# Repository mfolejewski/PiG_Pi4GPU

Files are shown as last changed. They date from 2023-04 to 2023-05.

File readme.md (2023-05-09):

# PiG (Pi4GPU)
Raspberry Pi CM4 carrier board for testing GPU cards

## Description

Dedicated carrier board for Raspberry Pi CM4 module (and compatible models) for testing high-performance GPU cards, enclosed in the standard PCIe form factor card.

Technical specification:
- ports: HDMI, 1GbE RJ45, 2x USB 2.0 host (Type A);
- power supply inputs: 12VDC DC barrel jack or 6-pin Molex (8A max.);
- microSD slot for CM4 Lite module;
- full 40-pin GPIO pin header;
- 4-pin fan socket (controlled by EMC2301) - 5/12V version supported;
- USB-C for flashing CM4 module;
- system and user LEDs;
- PCIe x4 edge connector (PCIe x1 lane only implemented);
- I2C diagnostics module for analog measurements (system power rails, 3.3V/5V/12V, voltage/current);

## License

Project published as Open Source Hardware (OSHW) under CERN OHL v1.2 (Open Hardware License).



Project has been certified as Open Source Hardware by the Open Source Hardware Association (OSHWA).

UID is (for v1): PL000014

UID is (for v2): PL000016

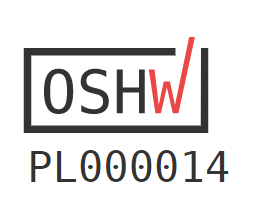
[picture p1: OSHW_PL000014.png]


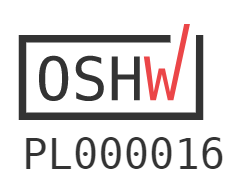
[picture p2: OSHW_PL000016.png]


https://certification.oshwa.org/pl000014.html

https://certification.oshwa.org/pl000016.html

## Press release

[Jeff Geerling Blog] (https://www.jeffgeerling.com/blog/2023/i-built-special-pcie-card-test-gpus-on-pi)

[Jeff Geerling video review] (https://www.youtube.com/watch?v=l9dItRUjQ0k)

[Hackster.io] (https://www.hackster.io/news/jeff-geerling-s-pig-makes-it-easier-to-experiment-with-pcie-add-in-boards-on-the-raspberry-pi-cm4-fdb977047521)

## Photos
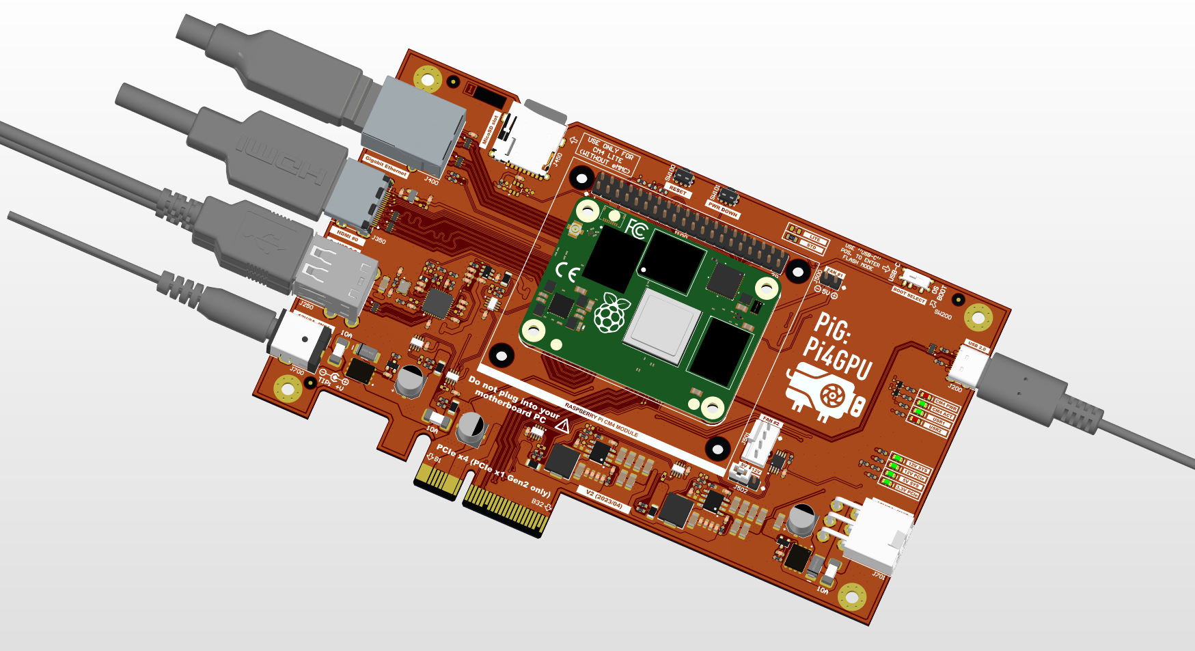
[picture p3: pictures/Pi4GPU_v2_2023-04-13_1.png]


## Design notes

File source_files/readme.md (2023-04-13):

## PCB design - source files
Here the design files (schematic, PCB, BOM) can be viewed by using interactive service (Altium 365 platform): 
- v1: https://365.altium.com/files/16D52066-6CA6-4288-87DA-874B35C8B3C8
- v2: https://365.altium.com/files/2EB381B2-202C-4C54-8FDE-9D991AE2ABAC

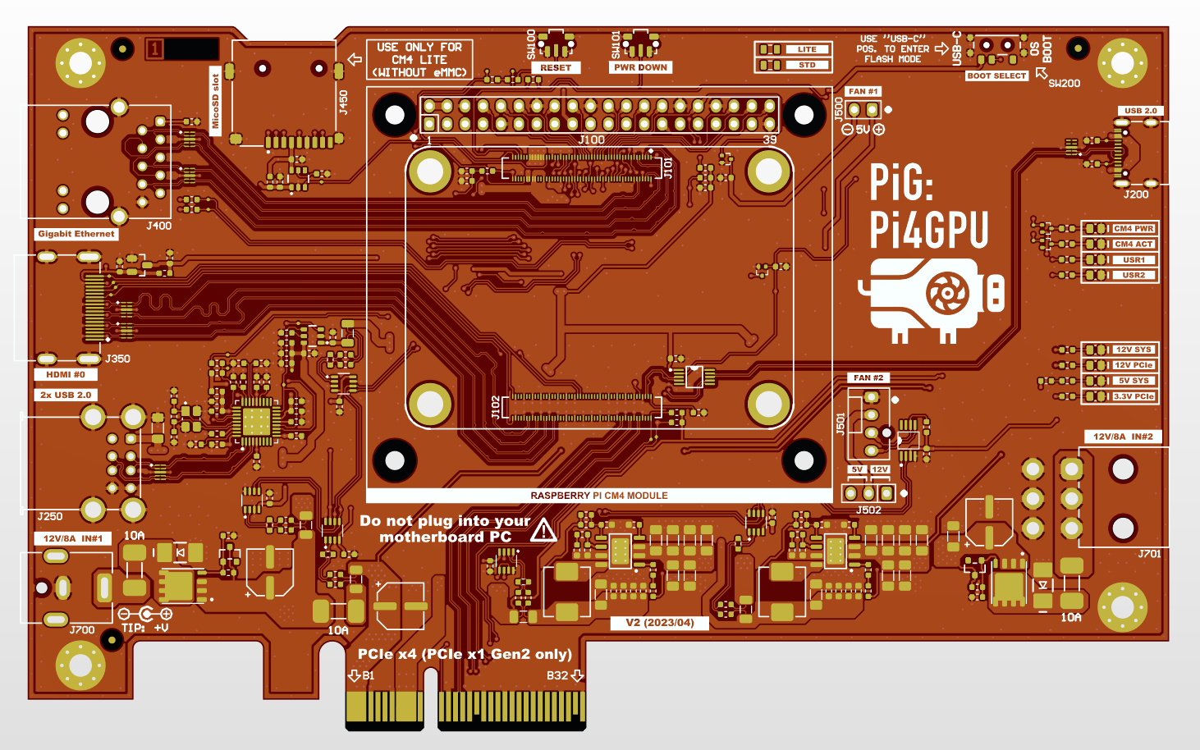
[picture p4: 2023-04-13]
pictures/Pi4GPU_v2_2023-04-13_5.png

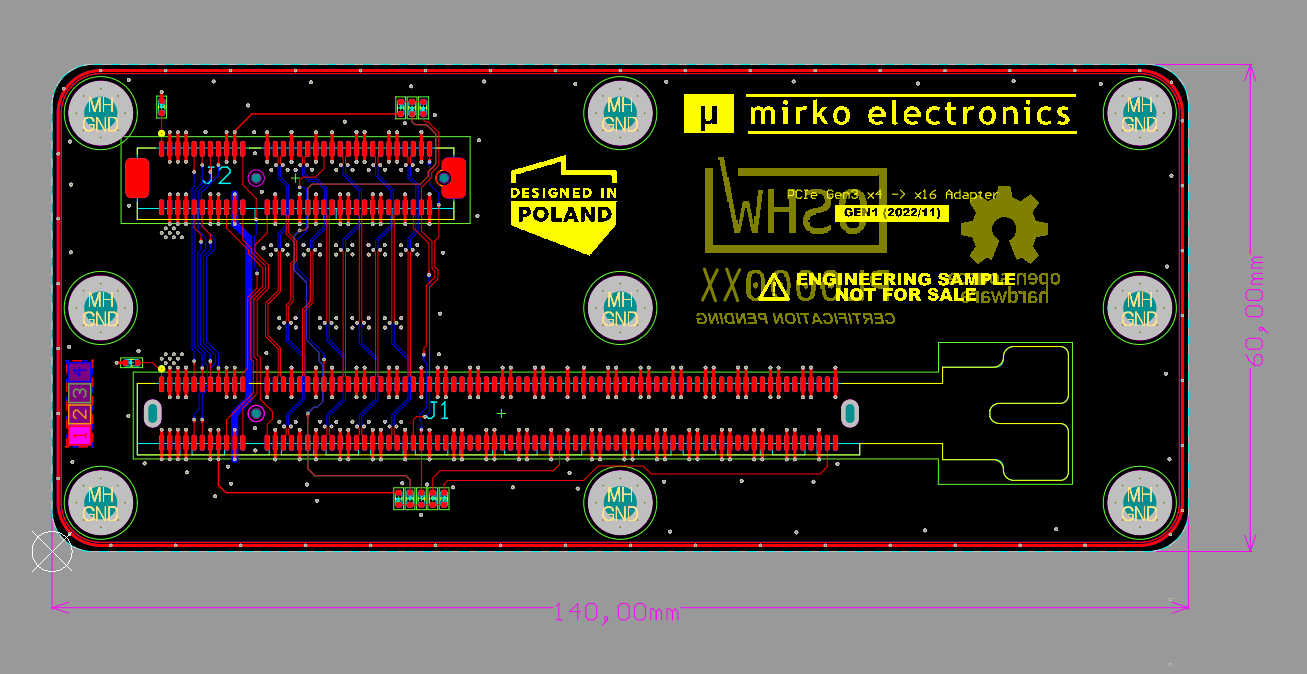
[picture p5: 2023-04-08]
pictures/PCIe_X4_X16_ADP_3.png

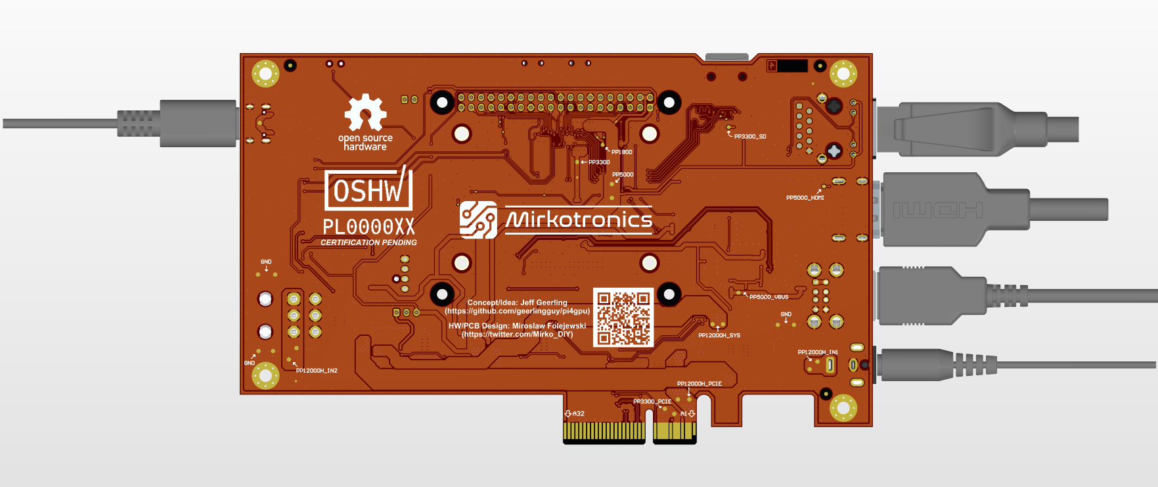
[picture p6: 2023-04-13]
pictures/Pi4GPU_v2_2023-04-13_3.png

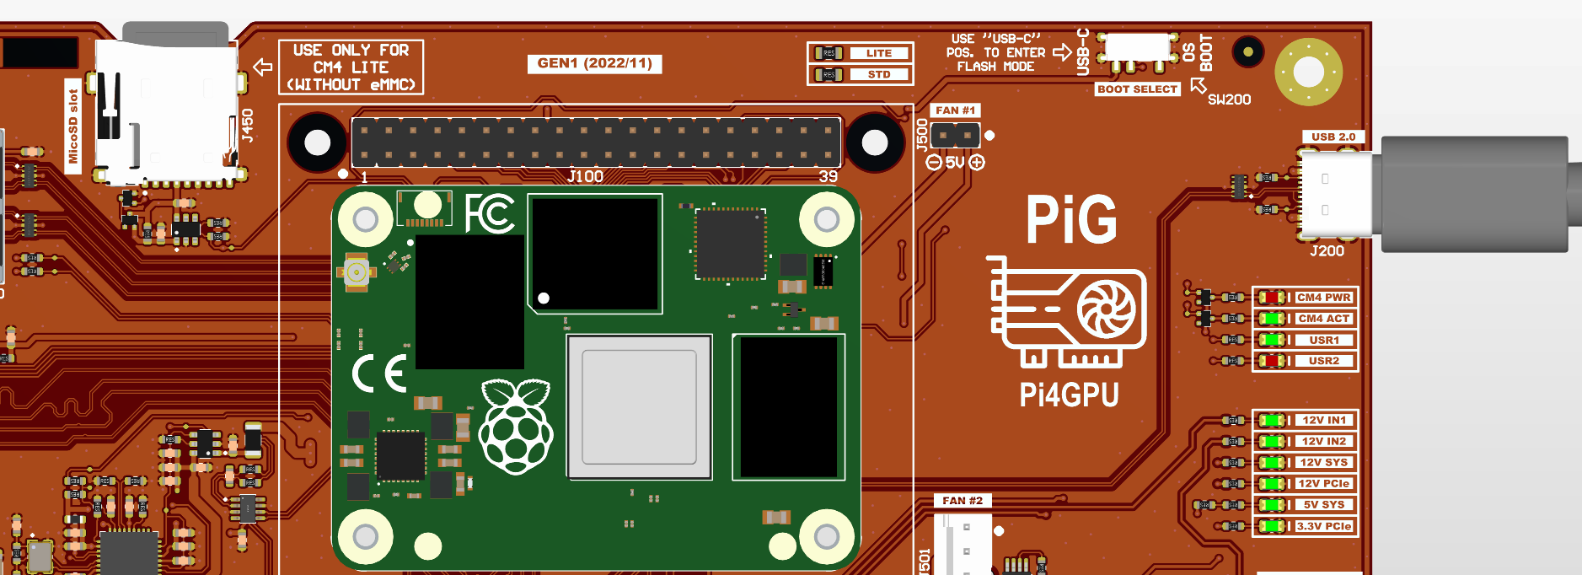
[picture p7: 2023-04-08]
pictures/Pi4GPU_2022-11-29_5.png

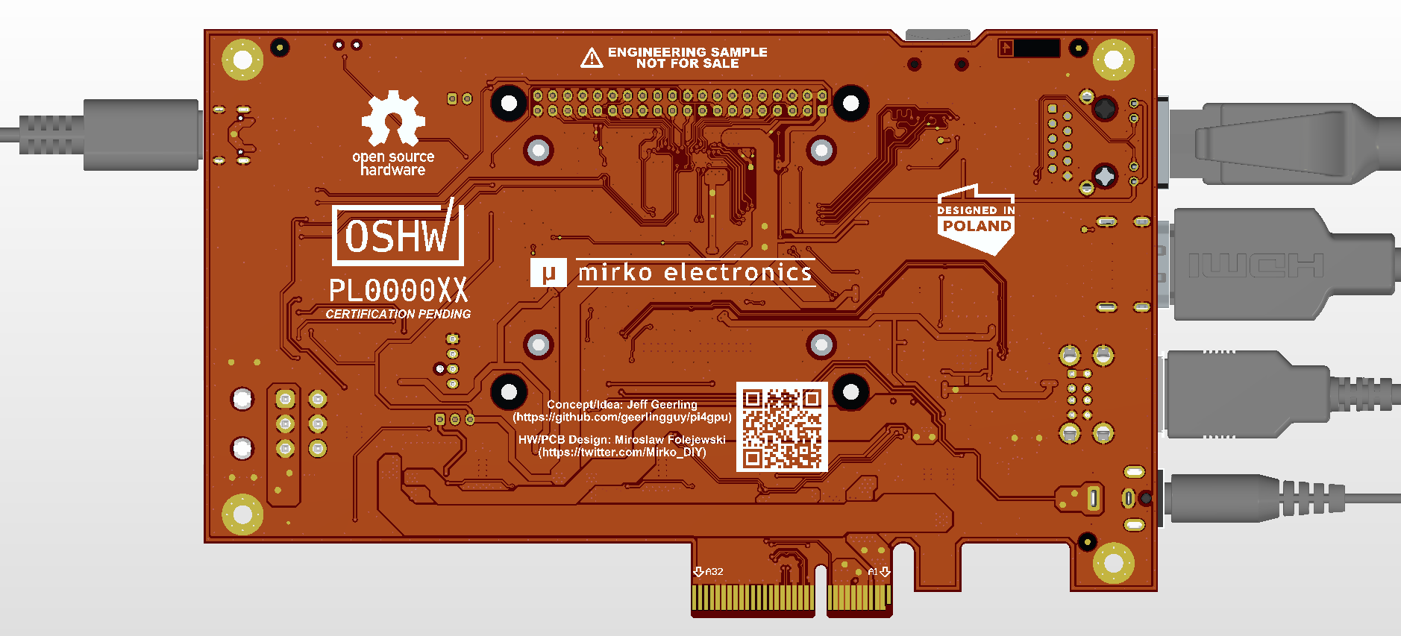
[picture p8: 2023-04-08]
pictures/Pi4GPU_2022-11-29_2.png

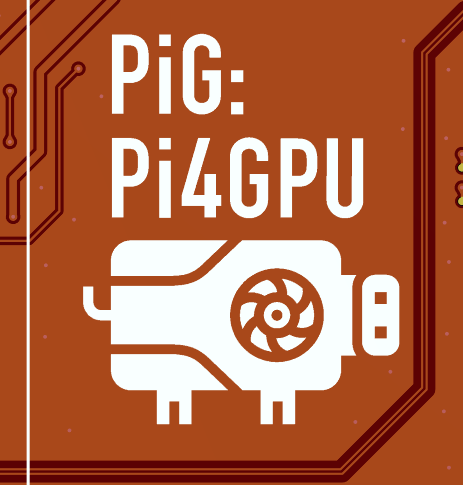
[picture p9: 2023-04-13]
pictures/Pi4GPU_v2_2023-04-13_4.png

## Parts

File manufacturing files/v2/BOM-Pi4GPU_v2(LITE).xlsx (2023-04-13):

Designator | Comment | Quantity | MPN | Manufacturer | Package (Case) | Footprint | Supplier 1 | Supplier Part Number 1
R450 | 0R | 1 | GENERIC | GENERIC | 0603 (1608) | RES_0603_R | LCSC | C21189
R900 | 0R | 1 | TBD | TBD | 0805 (2012) | RES_0805_R | LCSC | C17477
R807 | 0.004R | 1 | GENERIC | GENERIC | 1206 (3216) | RES_1206_R | LCSC | C5120913
R800, R806, R812 | 0.012R | 3 | GENERIC | GENERIC | 1206 (3216) | RES_1206_R | LCSC | C723448
R801 | 0.016R | 1 | GENERIC | GENERIC | 1206 (3216) | RES_1206_R | LCSC | C2904218
R200, R203 | 1k | 2 | TBD | Yageo Corporation | 0603 (1608) | RES_0603_R | LCSC | C21190
R256 | 1M | 1 | TBD | Yageo Corporation | 0603 (1608) | RES_0603_R | LCSC | C22935
C765, C781 | 1.2nF | 2 | GENERIC | GENERIC | 0603 (1608) | CAP_0603_R | LCSC | C1853470
R101, R102, R104, R106, R502 | 2k | 5 | TBD | Yageo Corporation | 0603 (1608) | RES_0603_R | LCSC | C22975
R760 | 2k26 | 1 | TBD | Yageo Corporation | 0603 (1608) | RES_0603_R | LCSC | C22904
L750, L751 | 3.3uH | 2 | FXL0624-3R3-M | Changjiang Microelectronics Tech | SMD | IND_SUM_0624CDMCCDS_700X660X240_R | LCSC | C524605
C256, C261 | 4u7 | 2 | GENERIC | GENERIC | 0603 (1608) | CAP_0603_R | LCSC | C19666
R201, R202 | 5k1 | 2 | TBD | Yageo Corporation | 0603 (1608) | RES_0603_R | LCSC | C23186
J700 | 8A, 2.0mm | 1 | PJ-063AH | CUI Devices | THT | CON_CUI_PJ-063AH | Mouser | 490-PJ-063AH
FUS700, FUS701, FUS702 | 10A/125VDC | 3 | 0679L9100-01 | Bel Fuse |  | FUS_2410_R | LCSC | C2838934
R103, R252, R253, R254, R255 | 10k | 5 | RC0603FR-0710KL | Yageo Corporation | 0603 (1608) | RES_0603_R | LCSC | C98220
R750, R755 | 10R | 2 | TBD | Yageo Corporation | 0603 (1608) | RES_0603_R | LCSC | C22859
C250, C252, C253, C254, C255, C451 | 10uF | 6 | GENERIC | GENERIC | 0603 (1608) | CAP_0603_R | LCSC | C19702
C755, C756, C757, C758, C771, C772, C773, C774 | 10uF/10V | 8 | GENERIC | GENERIC | 0603 (1608) | CAP_0603_R | LCSC | C19702
C703, C751, C752, C753, C761, C762, C763, C767, C768, C769, C777, C778, C779 | 10uF/35V | 13 | GENERIC | GENERIC | 1206 (3216) | CAP_1206_R | LCSC | C92797
R250 | 12k | 1 | GENERIC | GENERIC | 0603 (1608) | RES_0603_R | LCSC | C22790
R251, R753, R757 | 12k | 3 | TBD | Yageo Corporation | 0603 (1608) | RES_0603_R | LCSC | C22790
D700, D702 | 12V | 2 | MMBZ5242BLT3G | ON Semi |  | PKG_SOT23-3_TO236 | LCSC | C896784
R105, R501, R703, R709, R751, R756, R758 | 15k | 7 | TBD | Yageo Corporation | 0603 (1608) | RES_0603_R | LCSC | C22809
R754 | 15k | 1 | GENERIC | GENERIC | 0603 (1608) | RES_0603_R | LCSC | C22809
C266, C267 | 18pF | 2 | TBD | TBD | 0603 (1608) | CAP_0603_R | LCSC | C1647
R759 | 20k | 1 | GENERIC | GENERIC | 0603 (1608) | RES_0603_R | LCSC | C4184
X250 | 24.000MHz | 1 |  |  |  | OSC_3225_4P_R | LCSC | C5261153
J100 | 40pin (2x20pin) | 1 | GENERIC | GENERIC |  | CON_HDR_P254_2X20M_STR | LCSC | C124383
R752 | 47k | 1 | RC0603FR-0747KL | Yageo Corporation | 0603 (1608) | RES_0603_R | LCSC | C25819
R700, R701 | 100k | 2 | TBD | Yageo Corporation | 0603 (1608) | RES_0603_R | LCSC | C25803
C200, C257, C258, C259, C260, C262, C263, C350, C351, C400, C750, C760, C766, C776, C803 | 100nF | 15 | TBD | TBD | 0603 (1608) | CAP_0603_R | LCSC | C14663
C700, C702 | 100nF/50V | 2 | TBD | TBD | 0603 (1608) | CAP_0603_R | LCSC | C14663
R100, R107, R108, R109, R258 | 100R | 5 | TBD | Yageo Corporation | 0603 (1608) | RES_0603_R | LCSC | C22775
C251 | 100uF/6V3 | 1 | GENERIC | GENERIC | 1206 (3216) | CAP_1206_R | LCSC | C15008
C759, C775 | 100uF/10V | 2 | GENERIC | GENERIC | 1206 (3216) | CAP_1206_R | LCSC | C15008
F250 | 120 Ohm | 1 | TBD | TBD | 0603 (1608) | FER_0603_R | LCSC | C62708
C701, C704, C705 | 220uF/25V | 3 | EEEFTE221XAP | Panasonic | SMD SIZE D8 | CAP_SMD_SIZE_D8 | LCSC | C2918361
R400, R401 | 470R | 2 | TBD | Yageo Corporation | 0603 (1608) | RES_0603_R | LCSC | C23179
U352 | AP2331 | 1 | AP2331W-7 | Diodes Incorporated | SC59 | PKG_SOT23-3L_SC59_P190_R | LCSC | C460346
U250 | AP2553W6-7 | 1 | AP2553W6-7 | Diodes Incorporated | SOT26 | PKG_SOT23-6 | LCSC | C212302
U750, U751 | AP64501SP-13 | 2 | AP64501SP-13 | Diodes Incorporated |  | ICC_SOIC8N_TP_R | LCSC | C2071517
J500 | CON HDR 1x2 | 1 | GENERIC | GENERIC | THT | CON_HDR_P254_1X02_STR | LCSC | C492401
Q100, Q101 | DTA143ZE | 2 | DTA143ZET1G | On Semiconductor |  | PKG_SOT523_SC75_SOT416_P100_R | LCSC | C600679
Q200, Q500 | DTC143ZE | 2 | DTC143ZE |  |  | PKG_SOT523_SC75_SOT416_P100_R | LCSC | C248787
U200 | FSUSB42 | 1 | FSUSB42MUX | ON Semiconductor | MSOP-10 | ICC_MSOP10_300X300H110_P50_R | LCSC | C255478
LED100, LED500, LED700, LED701, LED750, LED751 | Green | 6 | NCD0805G1 | Foshan NationStar Optoelectronics | 0805 (2012) | LED_0805_GRN_R | LCSC | C84260
J400 | HY911130A | 1 | HY911130A | HanRun |  | CON_WRT_7499110122 | LCSC | C55679
J101, J102 | Mezzanine, 100pin, 3.0mm | 2 | DF40HC(3.0)-100DS-0.4V | Hirose | SMD | PCB_BLANK_COMP_SMD | LCSC | C424649
J450 | MicroSD Card (Slot) | 1 | TF-015 | TF-015 | SMD | CON_GCT_MEM2055_R | LCSC | C113206
J701 | Molex 2x3P 4.2mm | 1 | 039-30-1060 | Molex | THT | CON_MLX_039301060 | LCSC | C54904
PCB1 | PCB BARE BOARD | 1 | N/A | -
Q700, Q703 | PMOS | 2 | SI7149ADP-T1-GE3 | Vishay | PowerPAK-SO-8 | ICC_SO8_POWERPAK_490X590X112_P127_R | LCSC | C554002
U201, U252, U350, U351, U400, U401 | RCLAMP0524PA | 6 | RCLAMP0524PATCT | Semtech Corporation | TBD | ICC_SLP2510P8_250X100X60_P50_R | LCSC | C40960
LED101, LED501 | Red | 2 | NCD0805R1 | Foshan NationStar Optoelectronics | 0805 (2012) | LED_0805_RED_R | LCSC | C84256
MOD100 | RPi CM4 Module | 1 | CM4 Module | Raspberry Pi Foundation |  | MOD_RPI_CM4_SOCKET_P40_C300 | Farnell
SW200 | Slide switch | 1 | SS-3292S-L1 | XKB Connectivity | SMD | SWI_XKB_SS-3292S-L1 | LCSC | C397350
D701, D703 | SMAJ12A | 2 | SMAJ12A | Littelfuse |  | DIO_SMA_UNI_R | LCSC | C713694
SW100, SW101 | SPST | 2 | 436 333 033 816 | Wurth Elektronik | SMD | SWI_WRT_436333033816 | LCSC | C110293
J350 | Standdard HDMI (Type A) | 1 | HDMI-001 | BOOMELE | SMD | CON_HDMI_STD | LCSC | C138388
J200 | U262-161N-4BVC11 | 1 | U262-161N-4BVC11 | XKB Connectivity | SMD | CON_XKB_U262-161N-4BVC11 | LCSC | C319148
U251 | USB2512B | 1 | USB2512B | Microchip Technology |  | ICC_QFN36_600X600X100_P50_EP_R | LCSC | C626658
J250 | USB Type A (Dual) | 1 | TBD | TBD | THT | CON_USB_TYPE_A_2X | LCSC | C456021

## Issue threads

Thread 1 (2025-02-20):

Project tolerances and clearances

philm001, 2025-02-20:
Hello,

I am looking to this design for inspiration for a layout that I am working related to the one in here. I am currently using KiCAD. I was able to open the board layout but there are a number of DRC violations.

What are the tolerances and clearances for the board layout used to create the board.

philm001, 2025-02-21:
Never mind, I was able to come up with a solution and it clears the DRC

Closed 2025-02-21.

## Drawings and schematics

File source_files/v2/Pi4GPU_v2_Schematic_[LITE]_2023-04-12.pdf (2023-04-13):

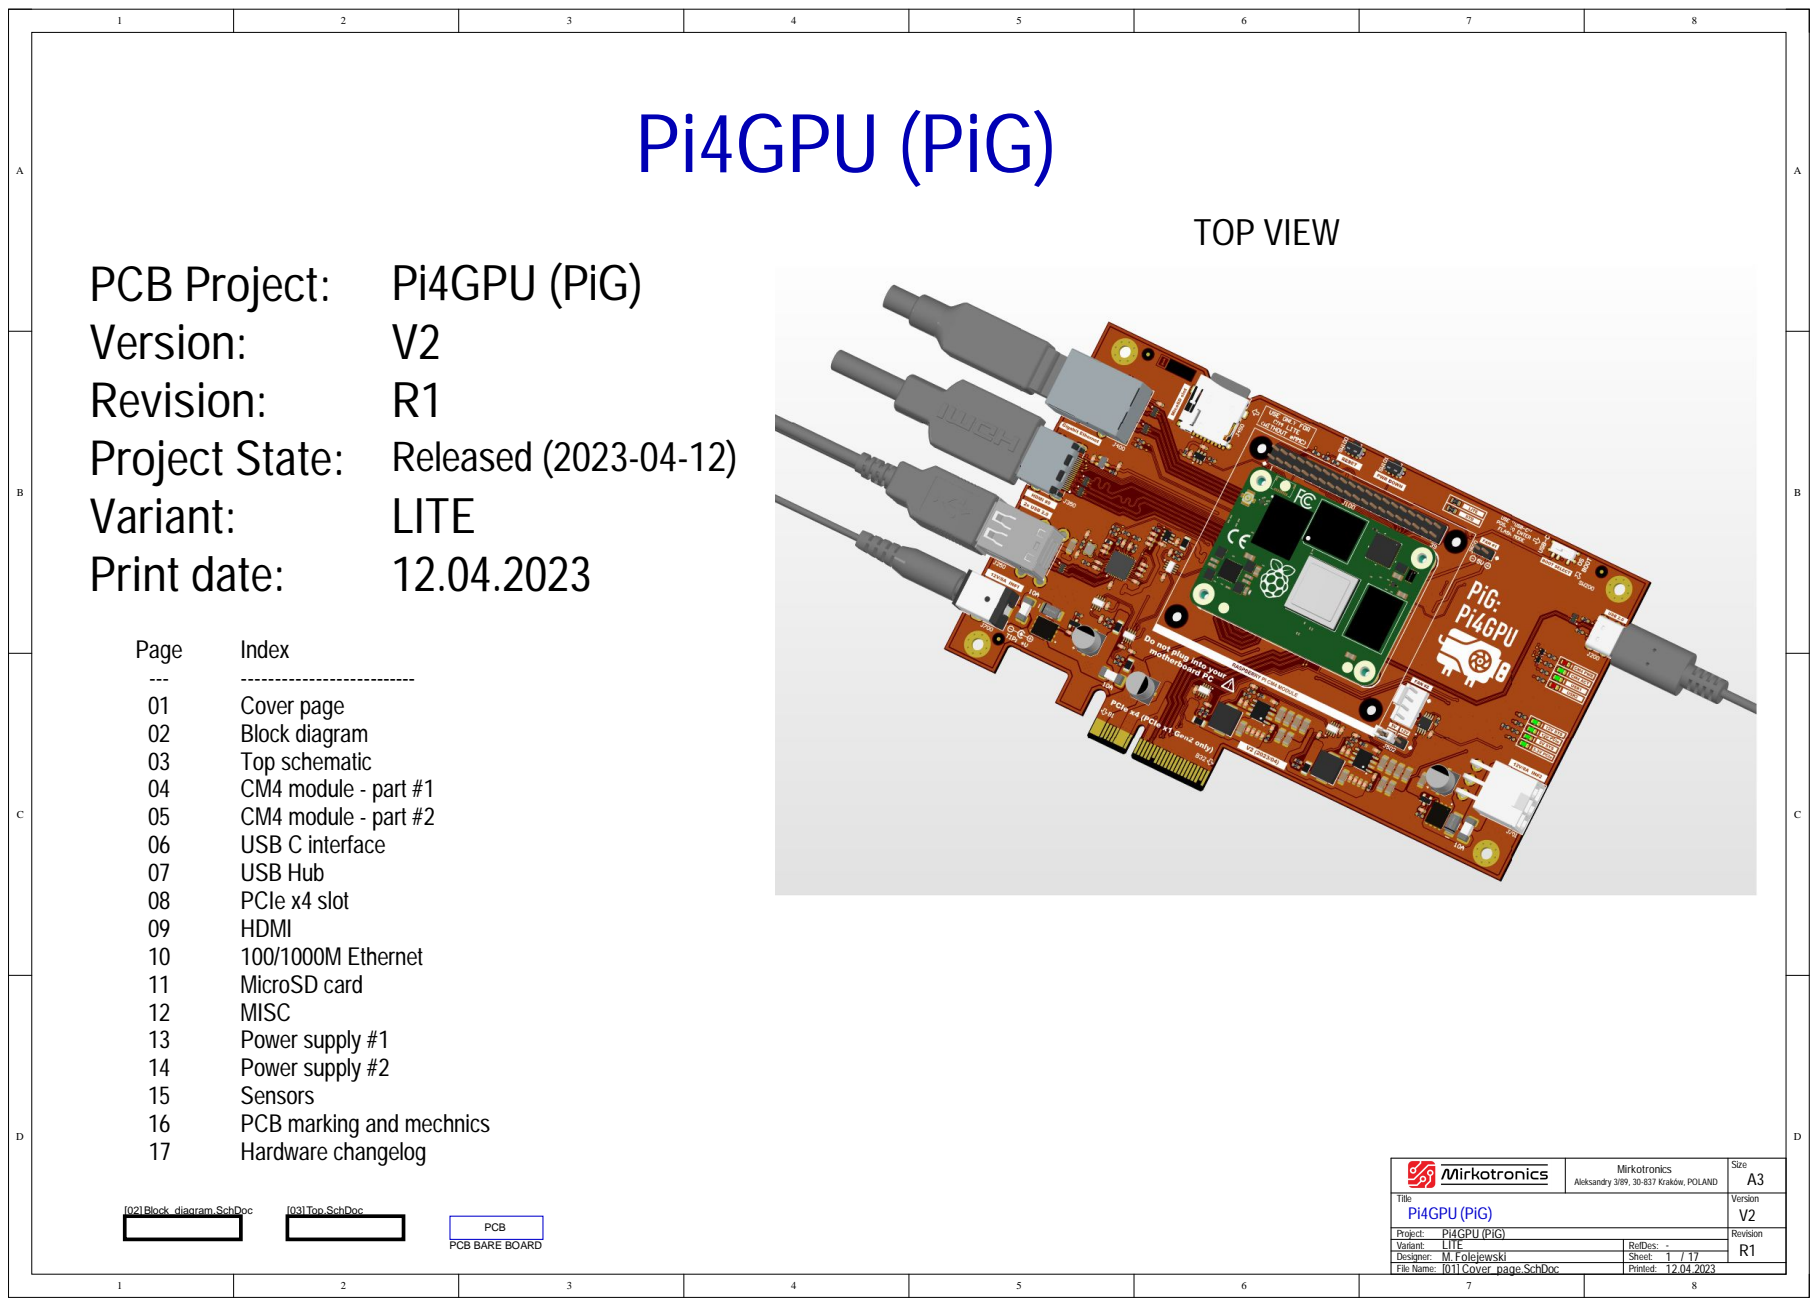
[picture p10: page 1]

Mirkotronics Aleksandry 3/89, 30-837 Kraków, POLAND | Size A3

Title Pi4GPU (PiG) | | Version V2

Revision R1
Variant: LITE
Designer: M. Folejewski
File Name: [01] Cover_page.SchDoc | Printed:

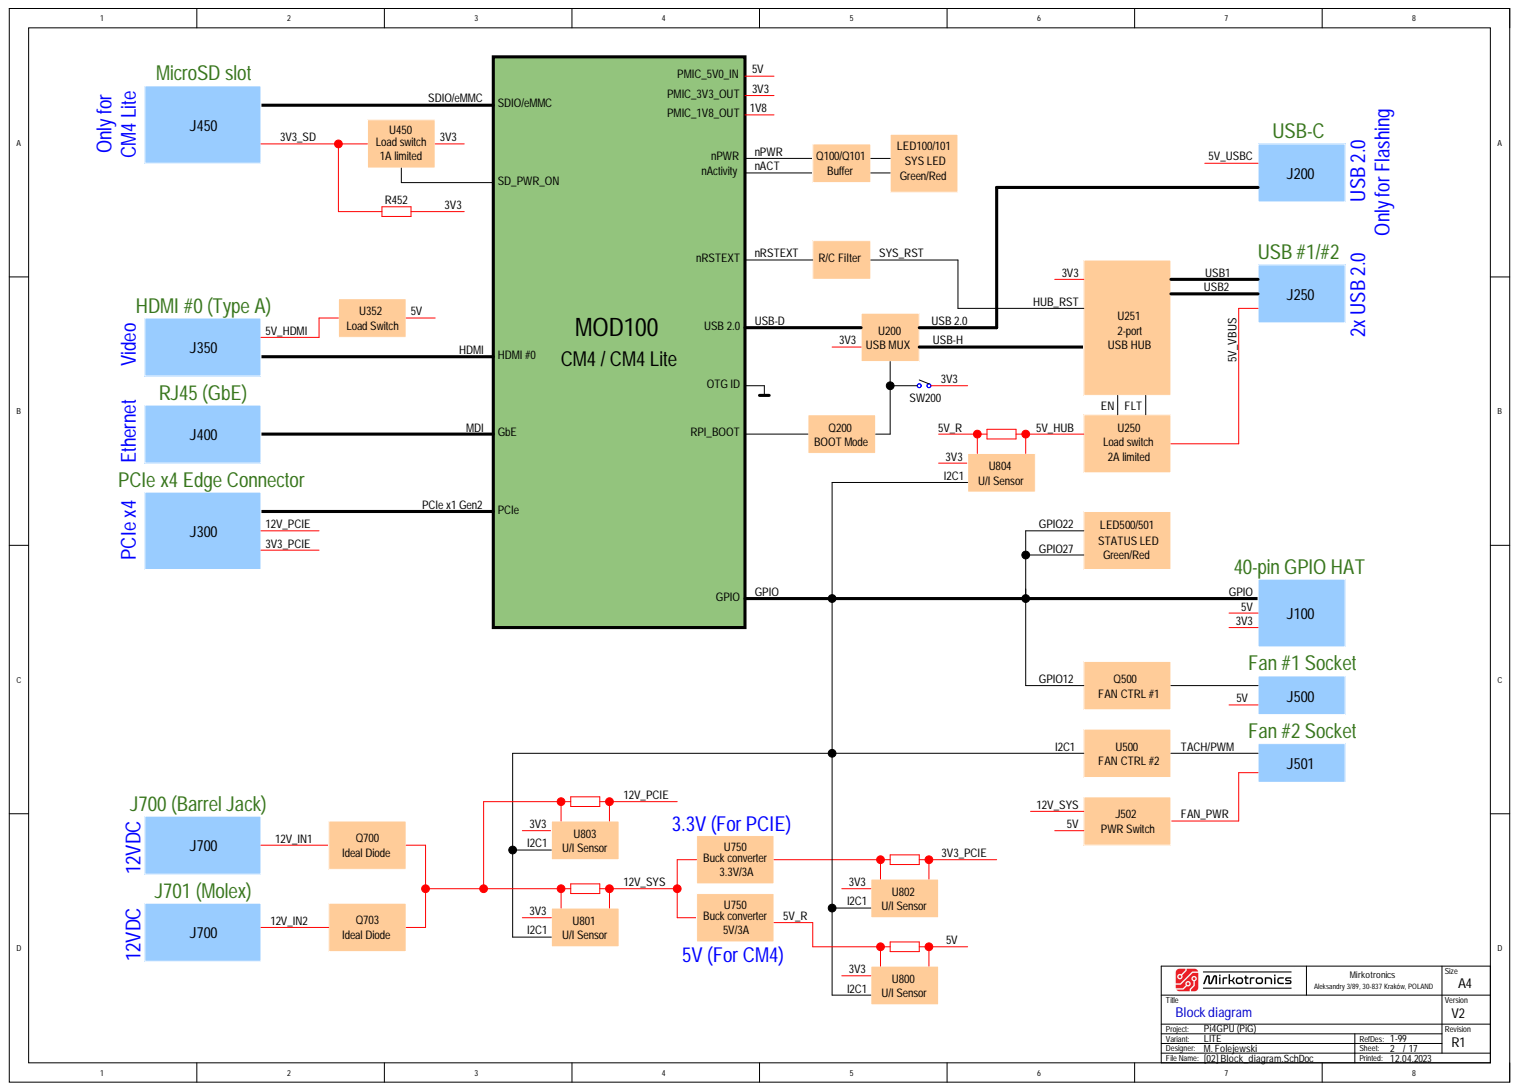
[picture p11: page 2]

SDIO/eMMC

Title Block diagram | Version V2

Revision R1
Variant: LITE

File Name: [02] Block_diagram.SchDoc | Printed:

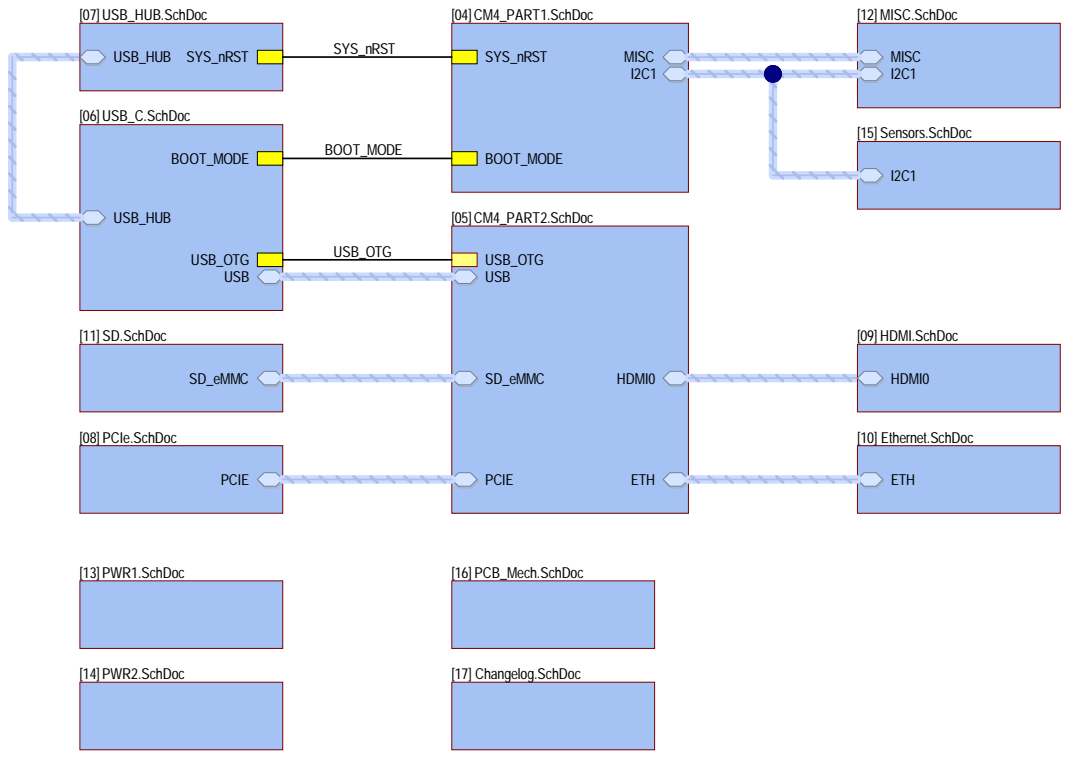
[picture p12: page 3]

Mirkotronics Aleksandry 3/89, 30-837 Kraków, POLAND | Size A4

Title Top schematic | | Version V2

Project: Pi4GPU (PiG) | | Revision R1
Variant: LITE | RefDes: 1-99

Sheet: 3 17 /

File Name: [03] TOP.SchDoc | Printed: 12.04.2023

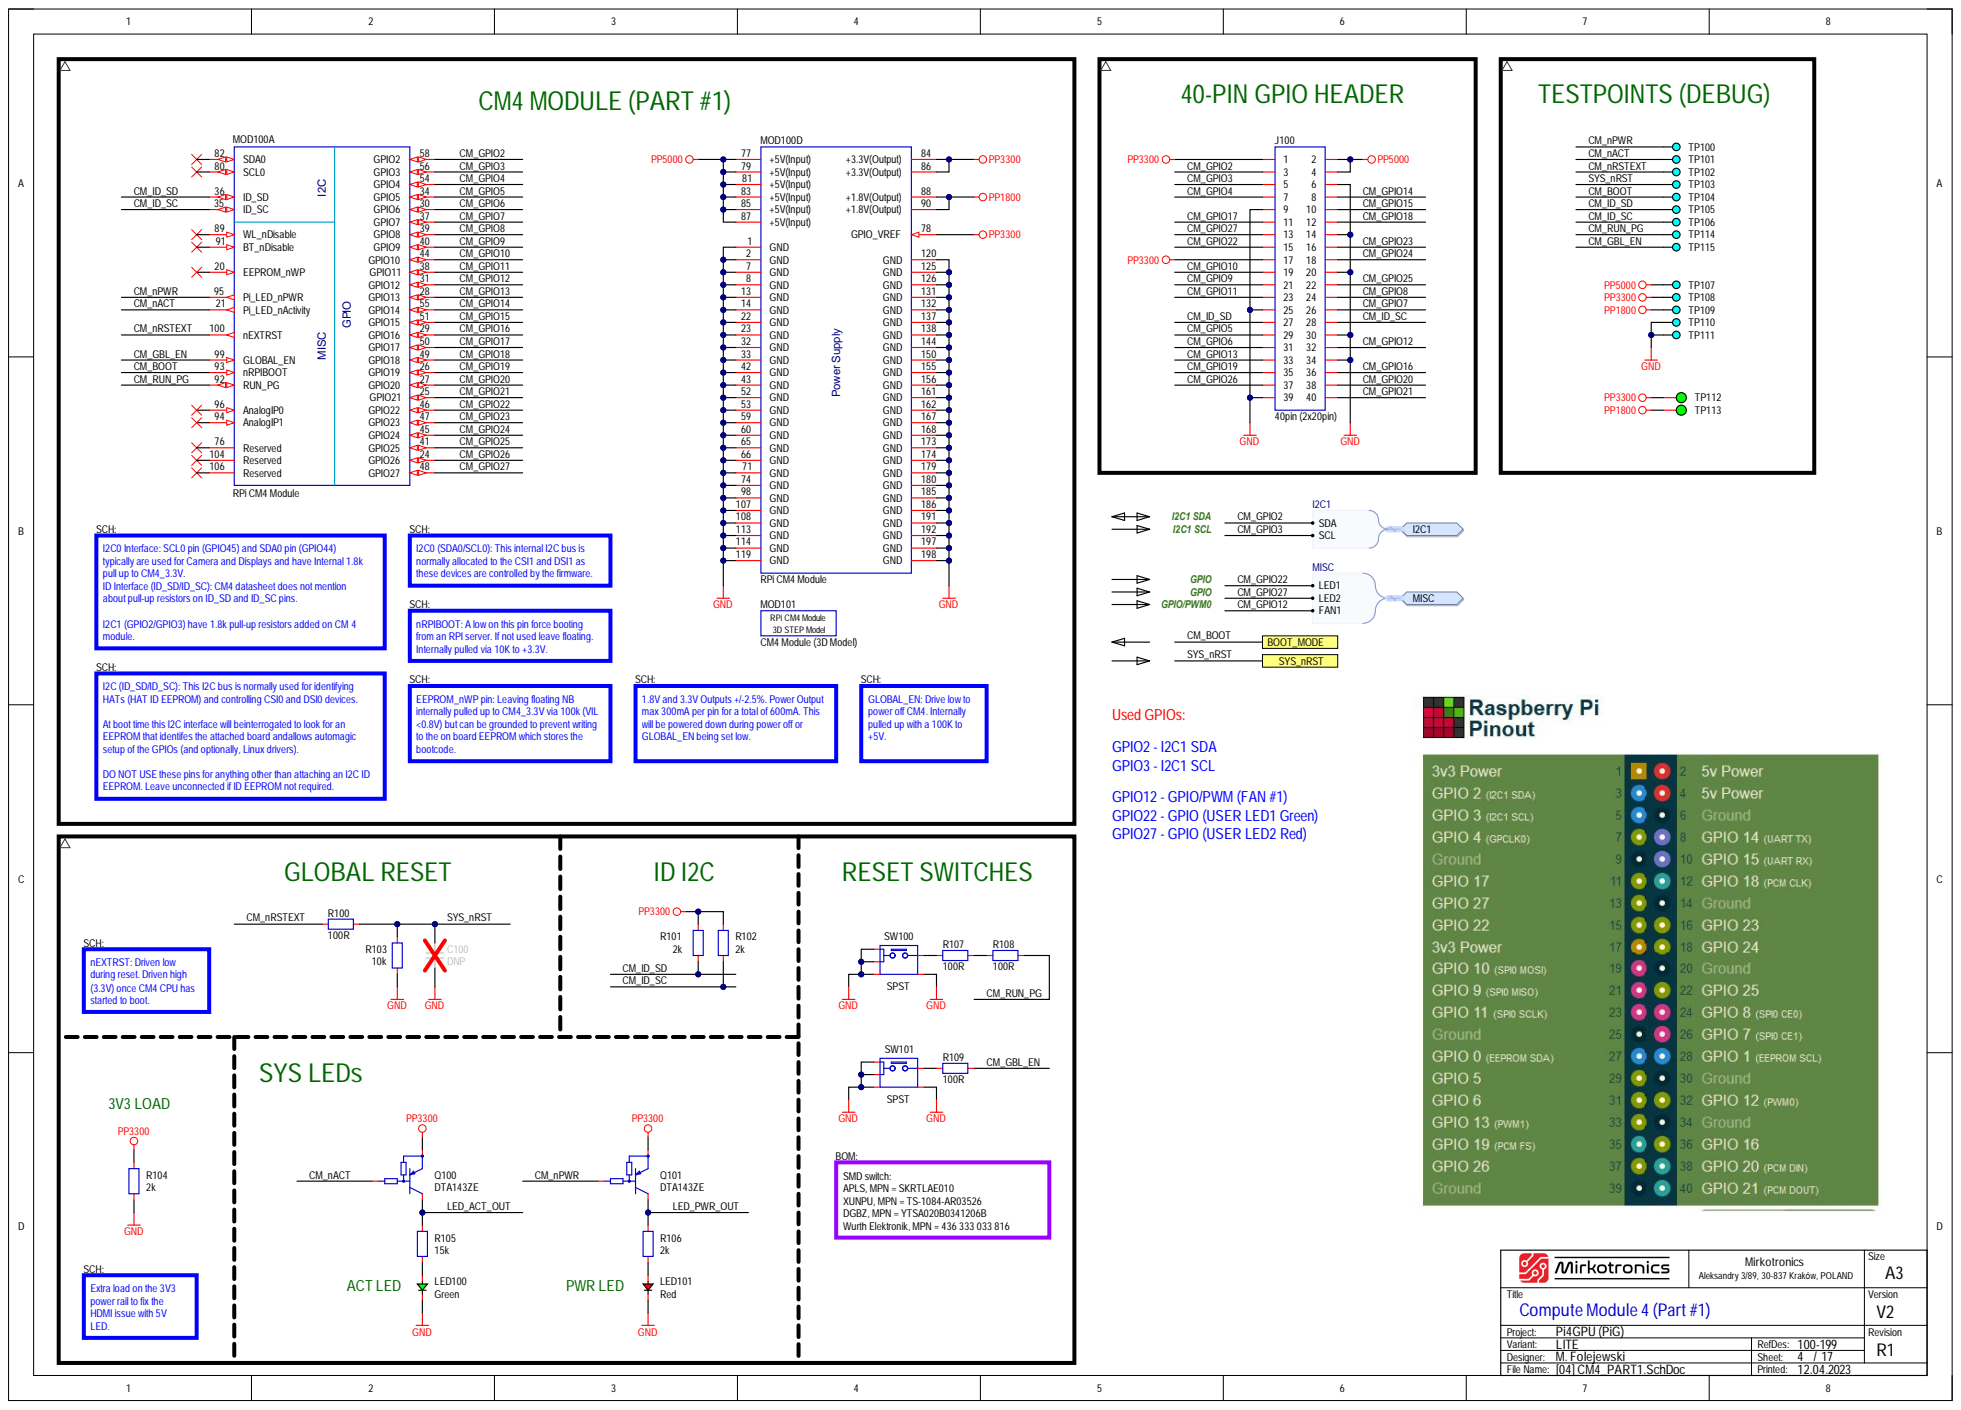
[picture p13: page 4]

SCH:
I2C0 Interface: SCL0 pin (GPIO45) and SDA0 pin (GPIO44)
typically are used for Camera and Displays and have Internal 1.8k
pull up to CM4_3.3V.
ID Interface (ID_SD/ID_SC): CM4 datasheet does not mention
about pull-up resistors on ID_SD and ID_SC pins.

I2C0 (SDA0/SCL0): This internal I2C bus is
normally allocated to the CSI1 and DSI1 as
these devices are controlled by the firmware.

nRPIBOOT: A low on this pin force booting
from an RPI server. If not used leave floating.
Internally pulled via 10K to +3.3V.

I2C1 (GPIO2/GPIO3) have 1.8k pull-up resistors added on CM4
module.

I2C (ID_SD/ID_SC): This I2C bus is normally used for identifying
HATs (HAT ID EEPROM) and controlling CSI0 and DSI0 devices.

EEPROM_nWP pin: Leaving floating NB
internally pulled up to CM4_3.3V via 100k (VIL
<0.8V) but can be grounded to prevent writing
to the on board EEPROM which stores the
bootcode.

1.8V and 3.3V Outputs +/-2.5%. Power Output
max 300mA per pin for a total of 600mA. This
will be powered down during power off or
GLOBAL_EN being set low.

GLOBAL_EN: Drive low to
power off CM4. Internally
pulled up with a 100K to

At boot time this I2C interface will beinterrogated to look for an
EEPROM that identifes the attached board andallows automagic
setup of the GPIOs (and optionally, Linux drivers).

DO NOT USE these pins for anything other than attaching an I2C ID
EEPROM. Leave unconnected if ID EEPROM not required.

nEXTRST: Driven low
during reset. Driven high
(3.3V) once CM4 CPU has
started to boot.

Mirkotronics Aleksandry 3/89, 30-837 Kraków, POLAND | Size A3

Extra load on the 3V3
power rail to fix the
HDMI issue with 5V
LED.

Title Compute Module 4 (Part #1) | | Version V2

Revision R1
Variant: LITE

File Name: [04] CM4_PART1.SchDoc | Printed:

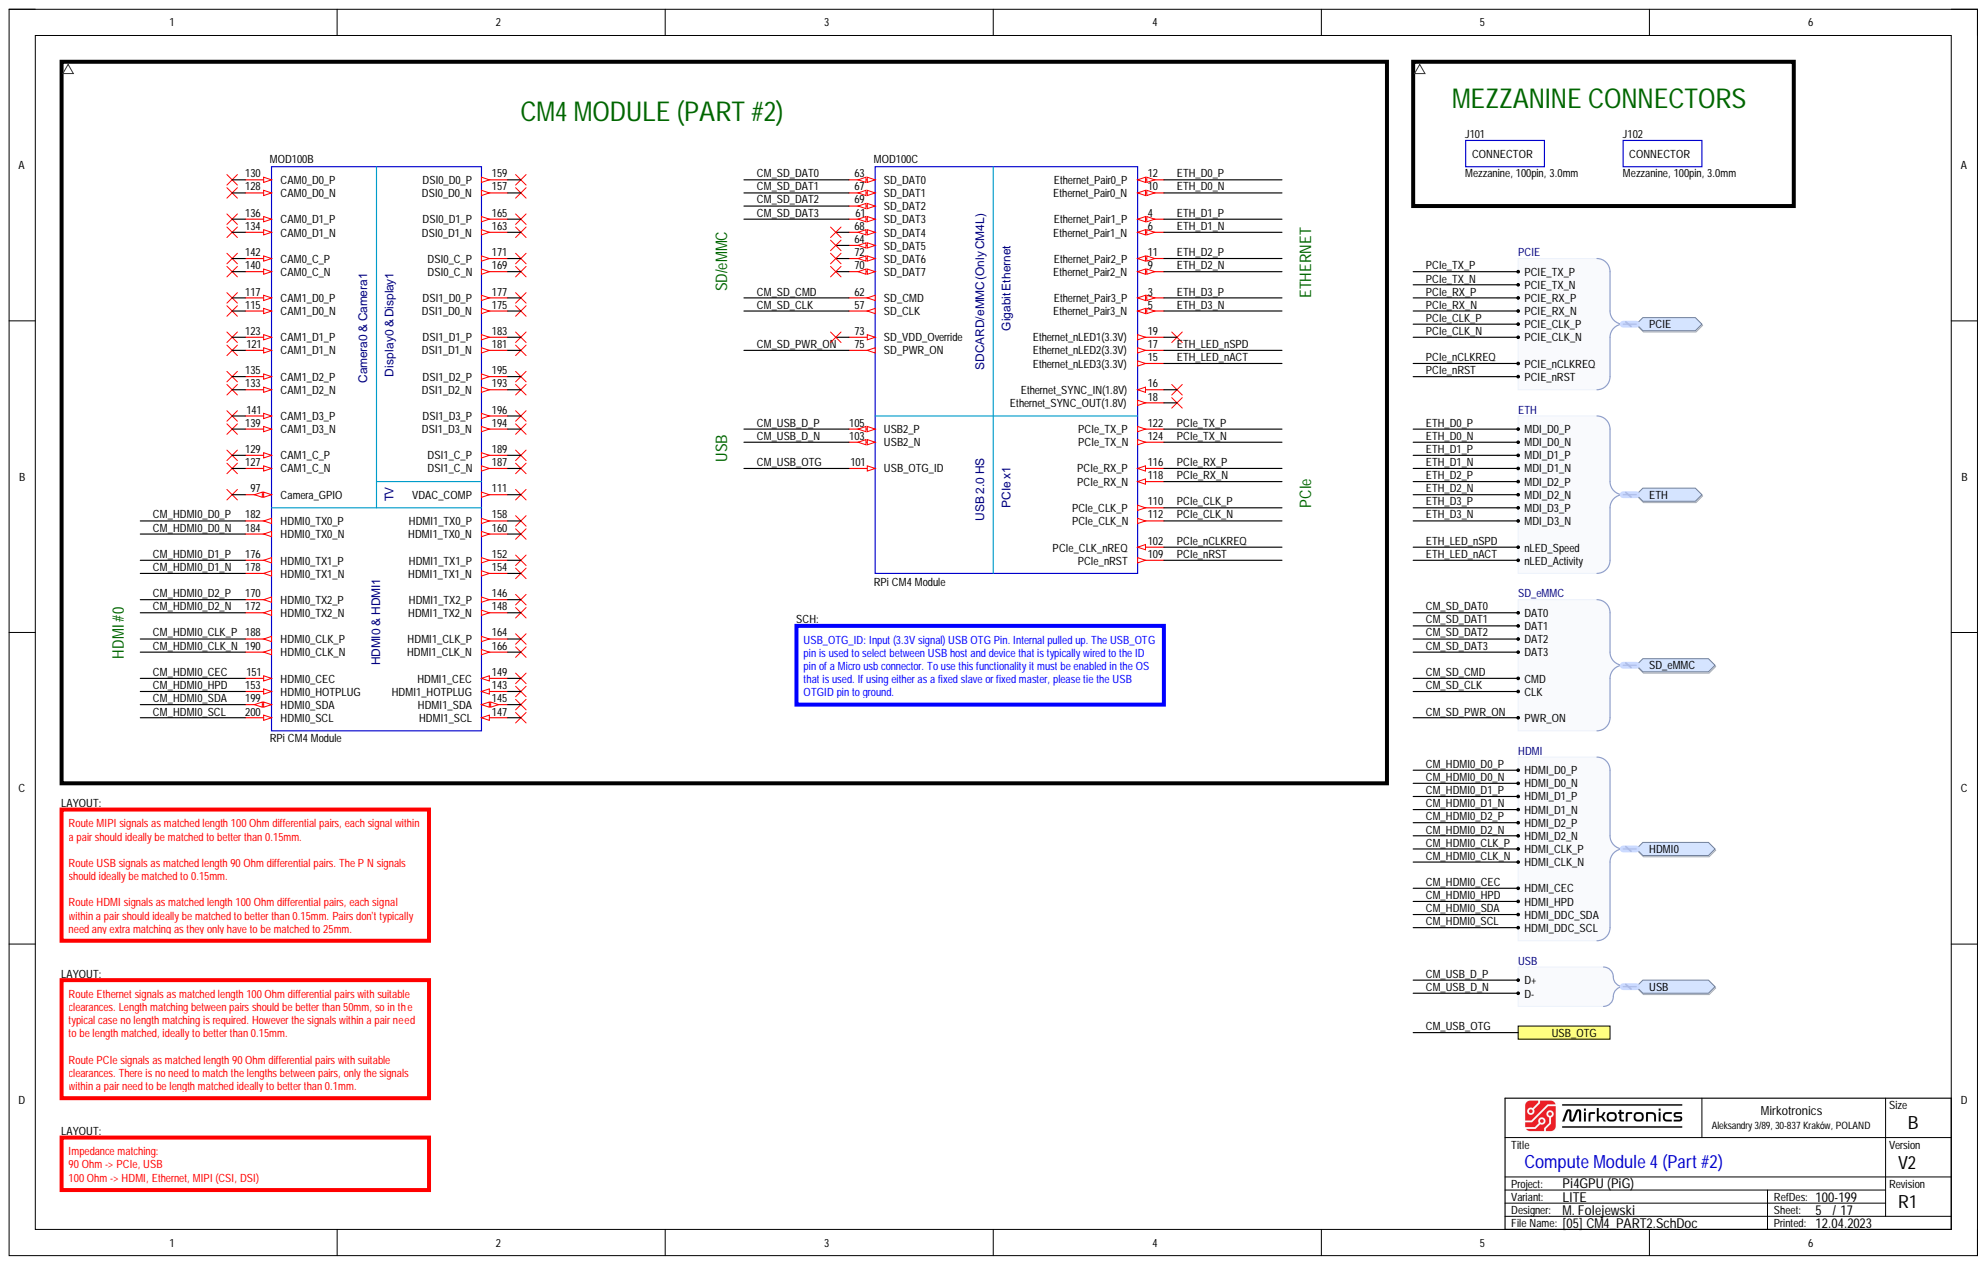
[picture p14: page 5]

SDCARD/eMMC(Only CM4L) USB 2.0 HS

select between USB host and devi
connector. To use

Revi sion R1
Variant: LITE
M. Folejewski Designer: | Sheet:
Fi le Name: [05] CM4_PART2.SchDoc | Printed:

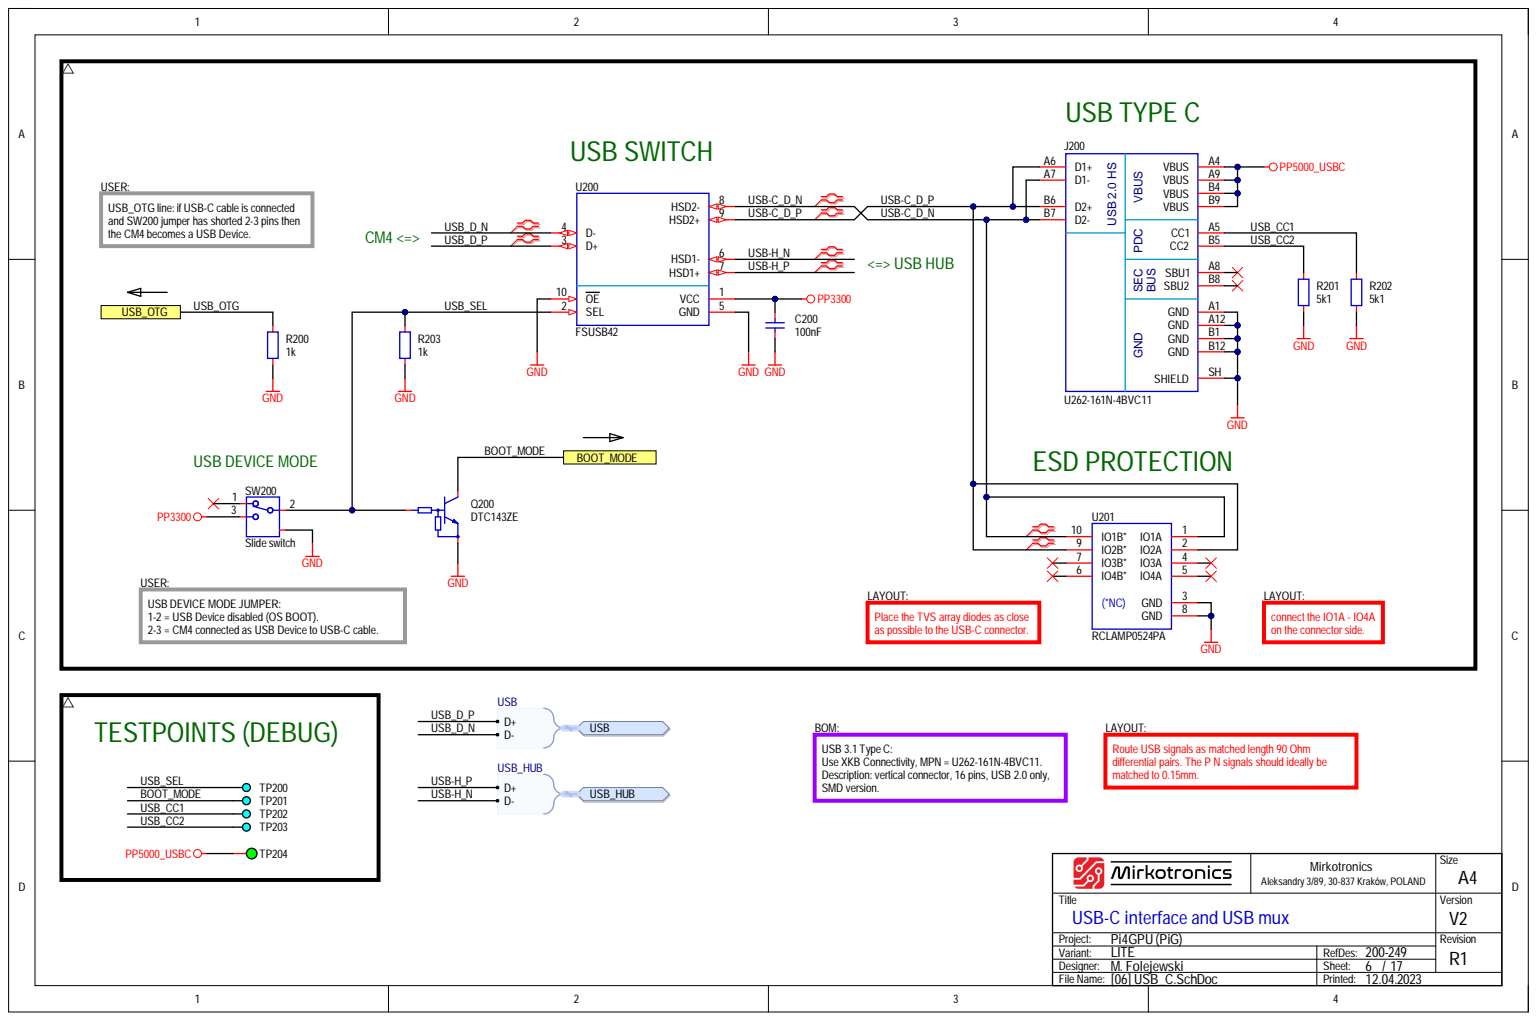
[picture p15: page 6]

D1+ A6 | VBUS
D1- A7 | A9
D2+ B6 | B4

GND VBUS PDC SEC

USER:
USB_OTG line: if USB-C cable is connected
and SW200 jumper has shorted 2-3 pins then
the CM4 becomes a USB Device.

USB DEVICE MODE JUMPER:
1-2 = USB Device disabled (OS BOOT).
2-3 = CM4 connected as USB Device to USB-C cable.

Place the TVS array diodes as close
as possible to the USB-C connector.

connect the IO1A - IO4A
on the connector side.

BOM:
USB 3.1 Type C:
Use XKB Connectivity, MPN = U262-161N-4BVC11.
Description: vertical connector, 16 pins, USB 2.0 only,
SMD version.

LAYOUT:
Route USB signals as matched length 90 Ohm
differential pairs. The P N signals should ideally be
matched to 0.15mm.

Mirkotronics Aleksandry 3/89, 30-837 Kraków, POLAND | Size A4

Title USB-C interface and USB mux | | Version V2

Project: Pi4GPU (PiG) | | Revision R1
Variant: LITE | RefDes: 200-249

File Name: [06] USB_C.SchDoc | Printed:

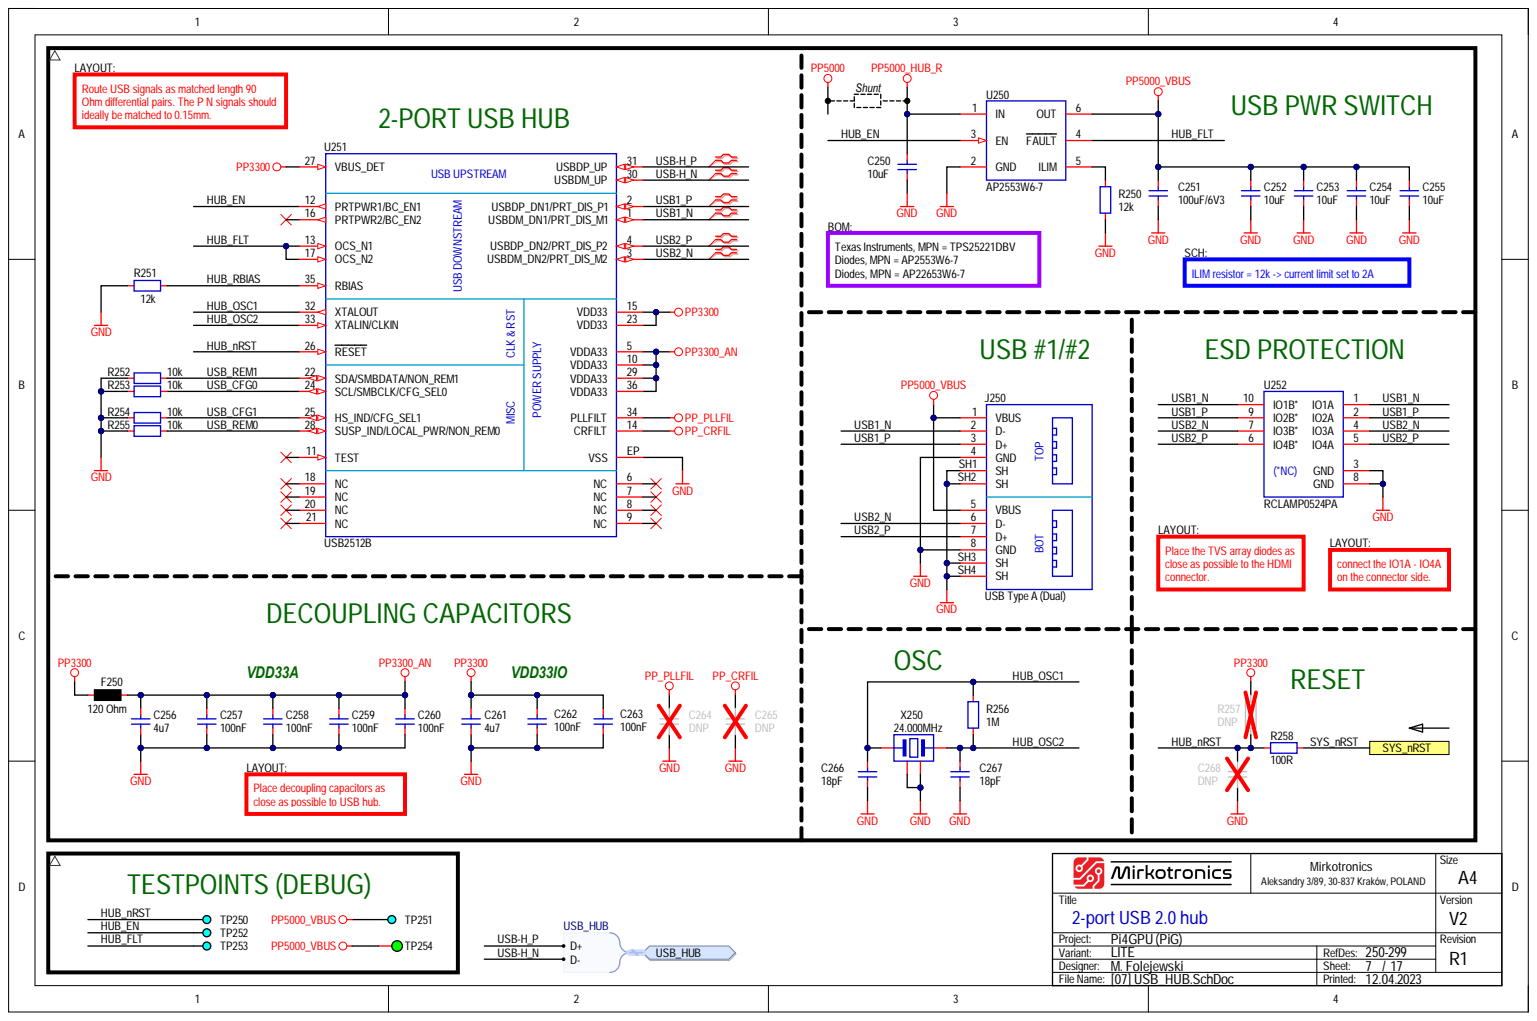
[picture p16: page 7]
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

SCH:
ILIM resistor = 12k -> current limit set to 2A

Place the TVS array diodes as
close as possible to the HDMI
connector.

connect the IO1A - IO4A
on the connector side.

Place decoupling capacitors as
close as possible to USB hub.

File Name: [07] USB_HUB.SchDoc | Printed:

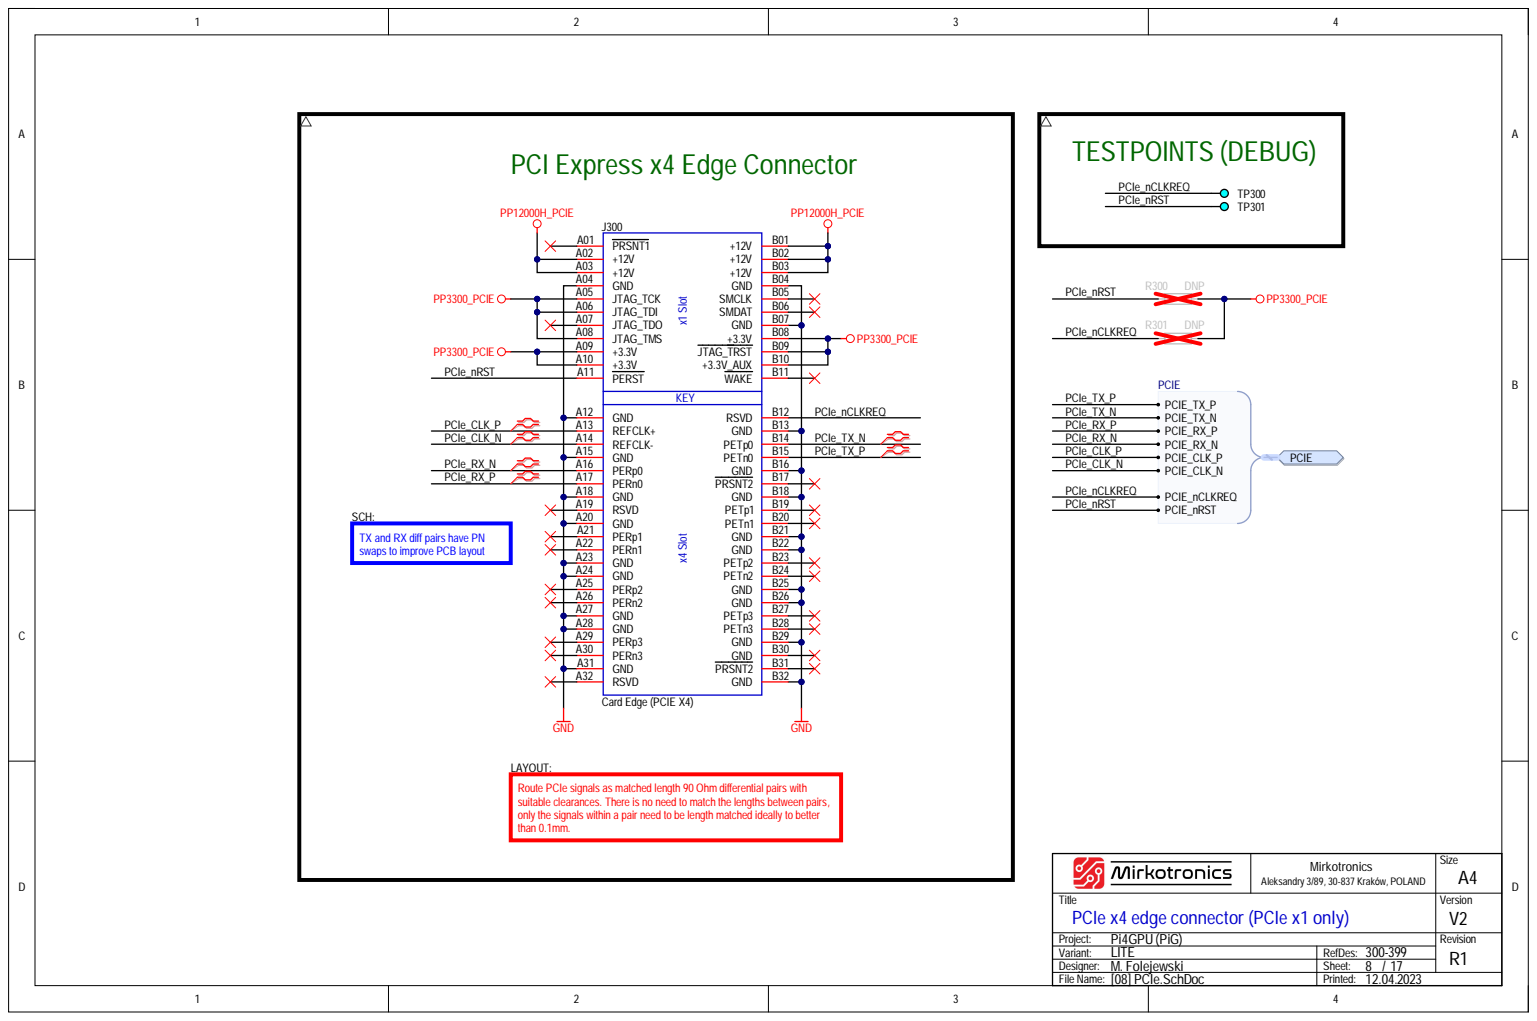
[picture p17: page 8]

PCI Express x4 Edge Connector

nd RX diff pairs have PN
ps to improve PCB layout

LAYOU
Route PCIe signals as matched le
suita
only the signals within a pair need to be le
tha

here is no need to match the le

ngth matched ideally to better

Mirkotro n i cs A leksandry 3/89, 30-837 Kraków, POLAND | Siz e A4

Titl e PCIe x4 edge connector (PCIe x1 only) | | Ve rsion V2
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

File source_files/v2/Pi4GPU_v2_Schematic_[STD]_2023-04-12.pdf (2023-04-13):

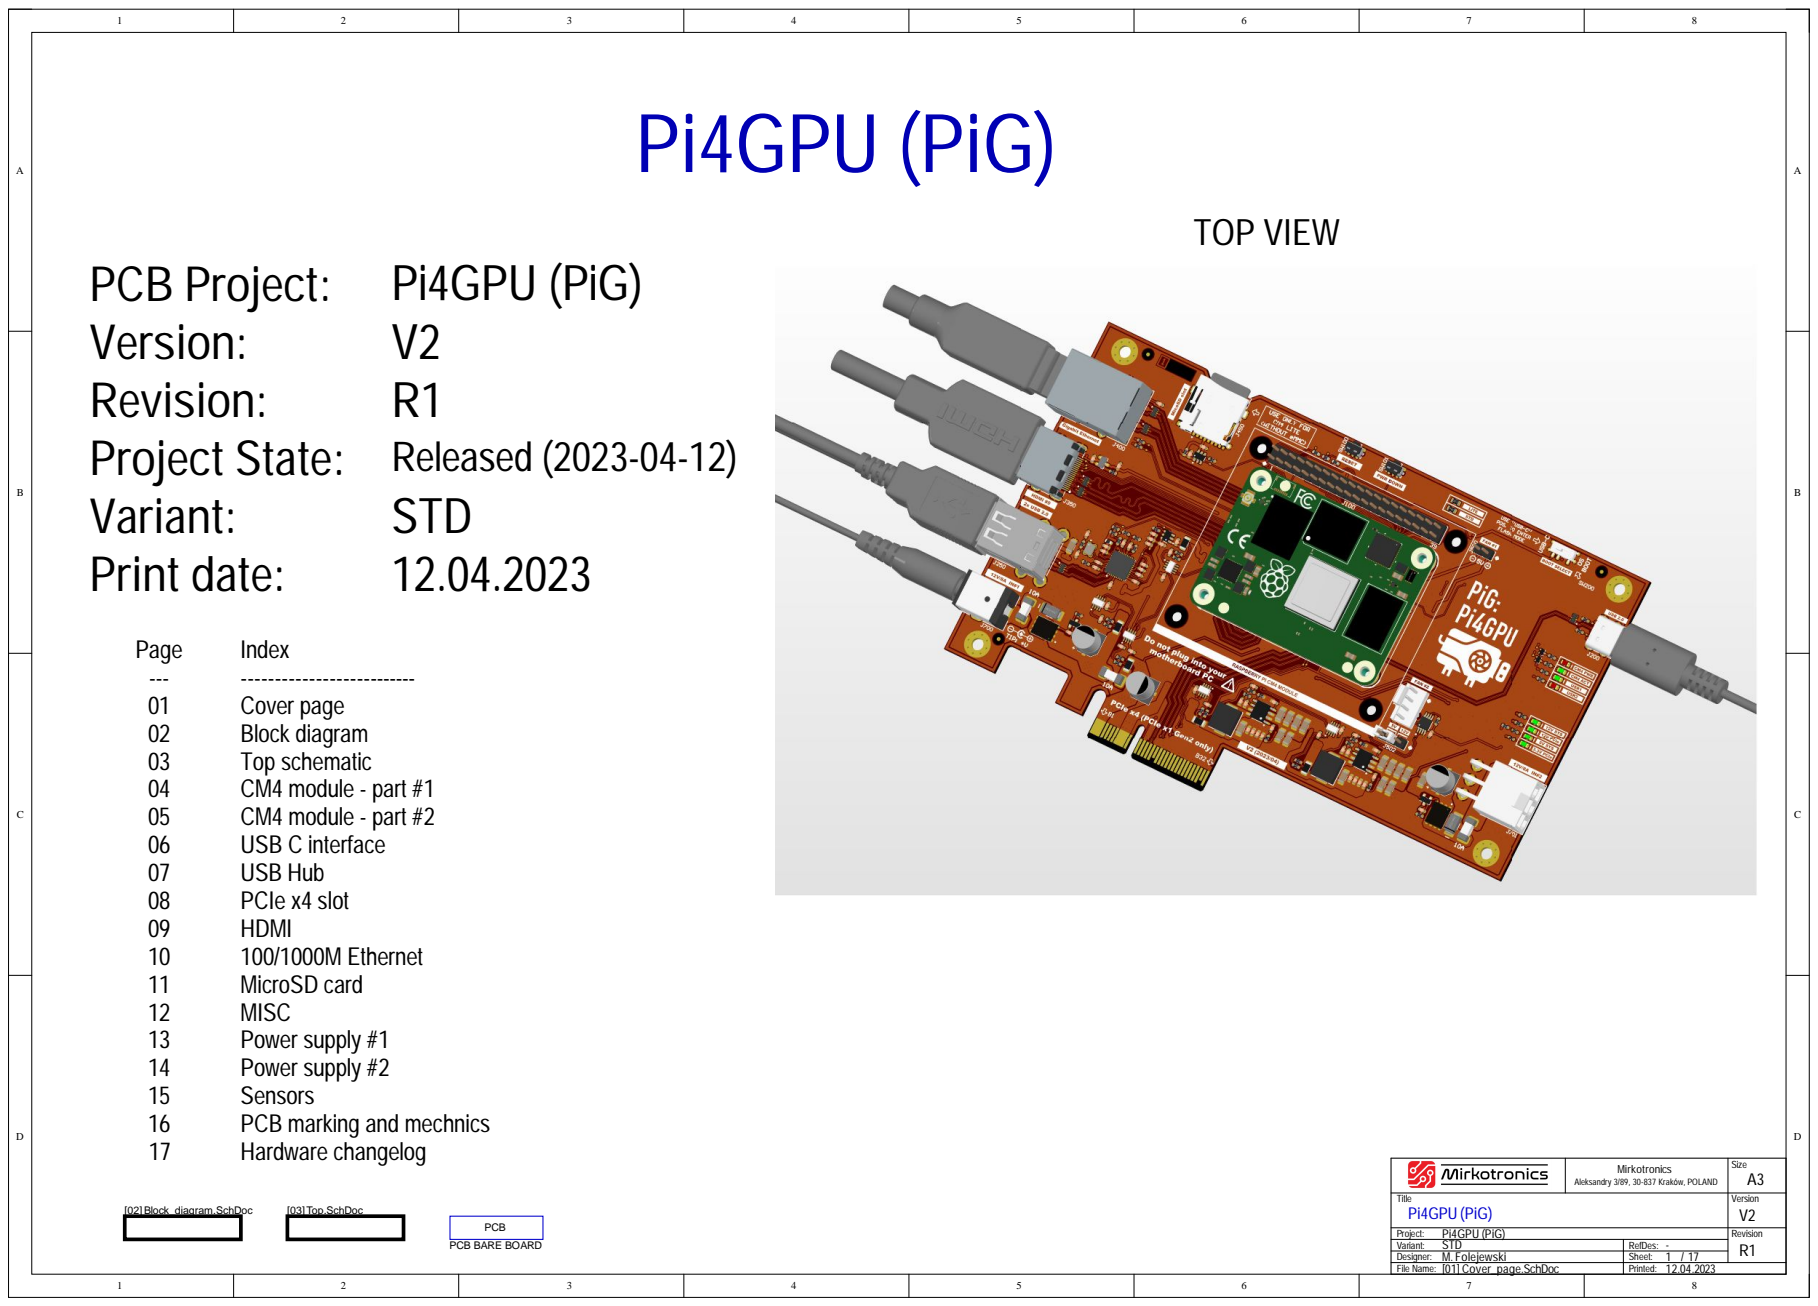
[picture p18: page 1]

Mirkotronics Aleksandry 3/89, 30-837 Kraków, POLAND | Size A3

Title Pi4GPU (PiG) | | Version V2

Revision R1
Variant: STD
Designer: M. Folejewski
File Name: [01] Cover_page.SchDoc | Printed:

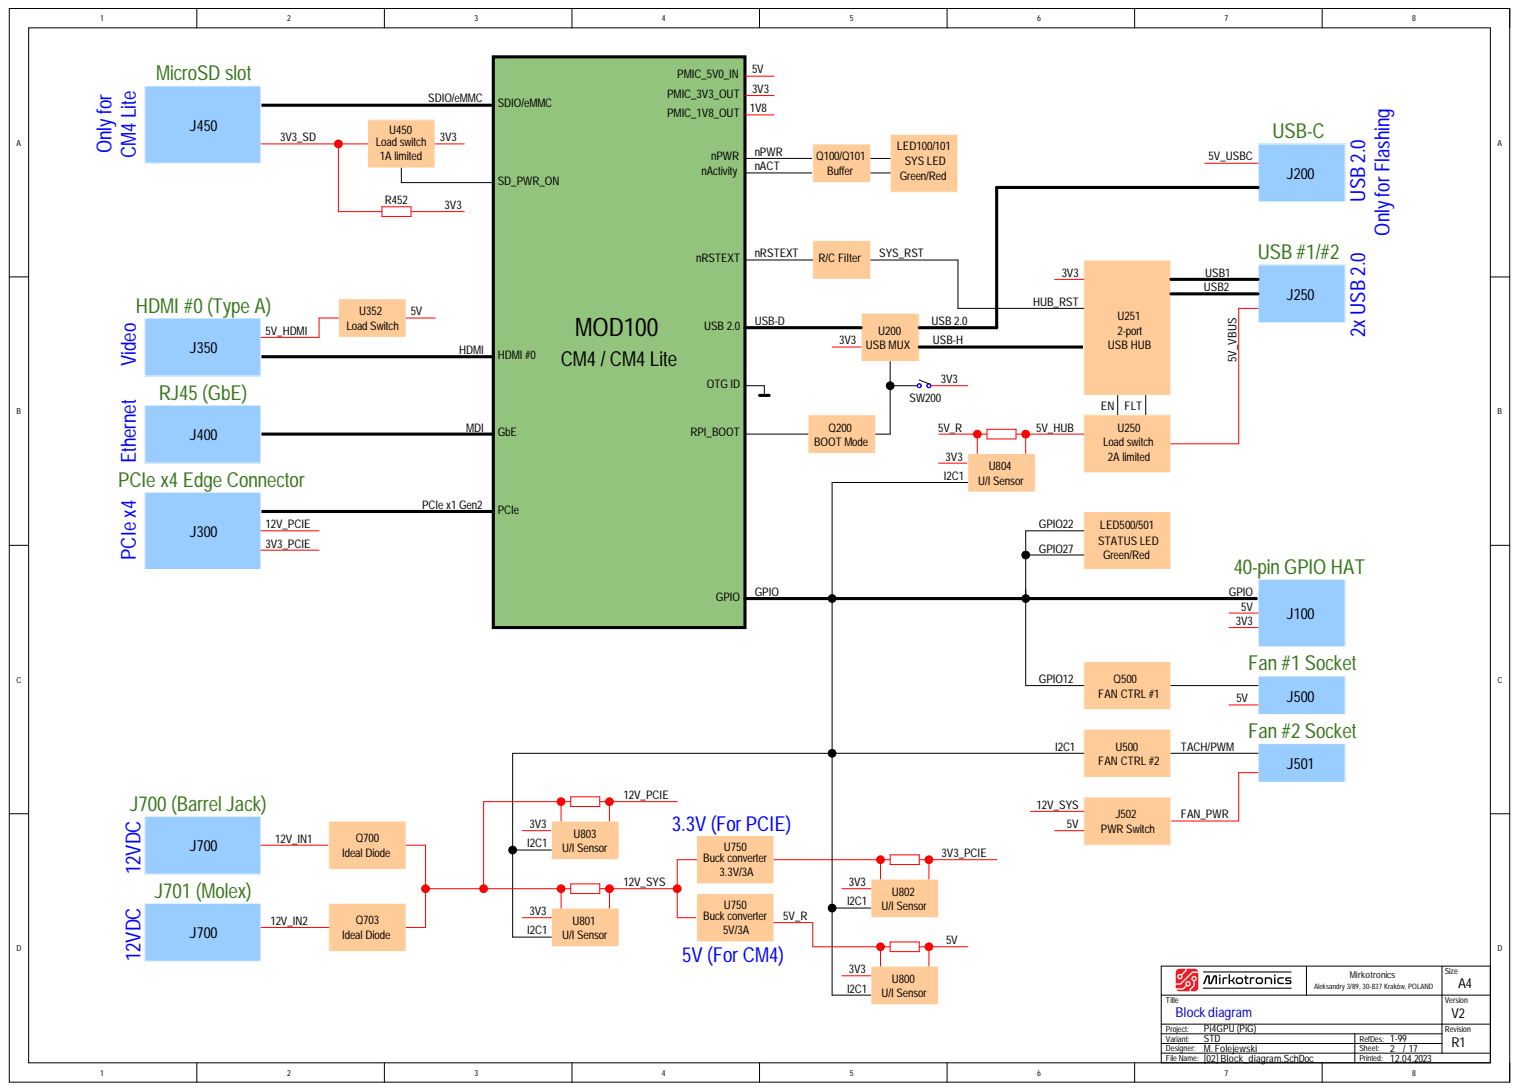
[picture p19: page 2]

SDIO/eMMC

Title Block diagram | Version V2

Revision R1
Variant: STD

File Name: [02] Block_diagram.SchDoc | Printed:


Mirkotronics Aleksandry 3/89, 30-837 Kraków, POLAND | Size A4

Title Top schematic | | Version V2

Project: Pi4GPU (PiG) | | Revision R1
Variant: STD | RefDes: 1-99

Sheet: 3 17 /

File Name: [03] TOP.SchDoc | Printed: 12.04.2023

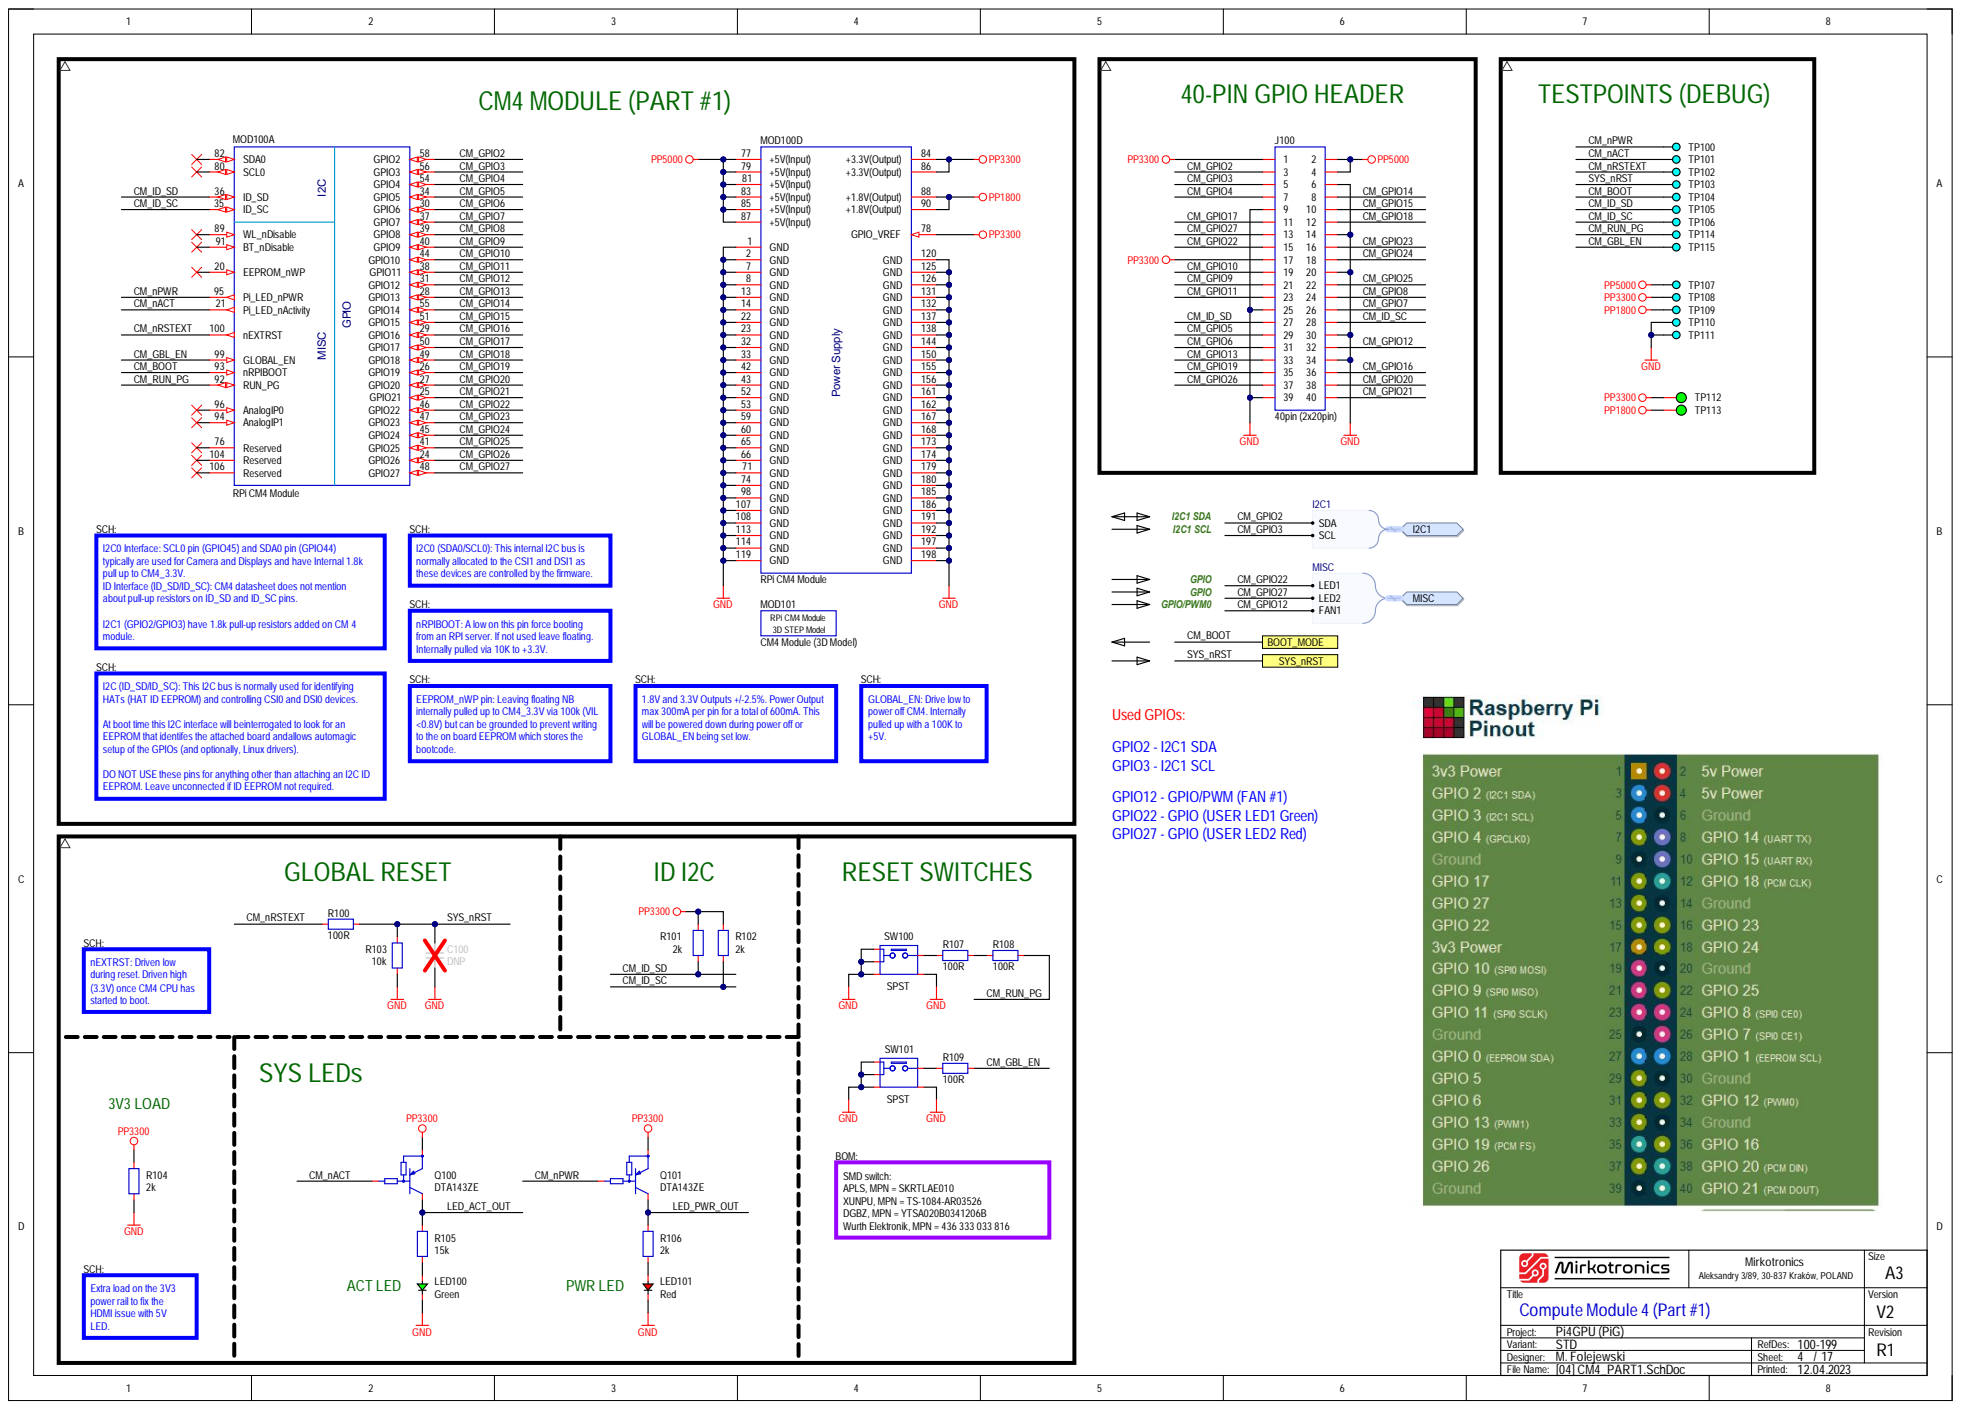
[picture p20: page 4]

SCH:
I2C0 Interface: SCL0 pin (GPIO45) and SDA0 pin (GPIO44)
typically are used for Camera and Displays and have Internal 1.8k
pull up to CM4_3.3V.
ID Interface (ID_SD/ID_SC): CM4 datasheet does not mention
about pull-up resistors on ID_SD and ID_SC pins.

I2C0 (SDA0/SCL0): This internal I2C bus is
normally allocated to the CSI1 and DSI1 as
these devices are controlled by the firmware.

nRPIBOOT: A low on this pin force booting
from an RPI server. If not used leave floating.
Internally pulled via 10K to +3.3V.

I2C1 (GPIO2/GPIO3) have 1.8k pull-up resistors added on CM4
module.

I2C (ID_SD/ID_SC): This I2C bus is normally used for identifying
HATs (HAT ID EEPROM) and controlling CSI0 and DSI0 devices.

EEPROM_nWP pin: Leaving floating NB
internally pulled up to CM4_3.3V via 100k (VIL
<0.8V) but can be grounded to prevent writing
to the on board EEPROM which stores the
bootcode.

1.8V and 3.3V Outputs +/-2.5%. Power Output
max 300mA per pin for a total of 600mA. This
will be powered down during power off or
GLOBAL_EN being set low.

GLOBAL_EN: Drive low to
power off CM4. Internally
pulled up with a 100K to

At boot time this I2C interface will beinterrogated to look for an
EEPROM that identifes the attached board andallows automagic
setup of the GPIOs (and optionally, Linux drivers).

DO NOT USE these pins for anything other than attaching an I2C ID
EEPROM. Leave unconnected if ID EEPROM not required.

nEXTRST: Driven low
during reset. Driven high
(3.3V) once CM4 CPU has
started to boot.

Mirkotronics Aleksandry 3/89, 30-837 Kraków, POLAND | Size A3

Extra load on the 3V3
power rail to fix the
HDMI issue with 5V
LED.

Title Compute Module 4 (Part #1) | | Version V2

Revision R1
Variant: STD

File Name: [04] CM4_PART1.SchDoc | Printed:

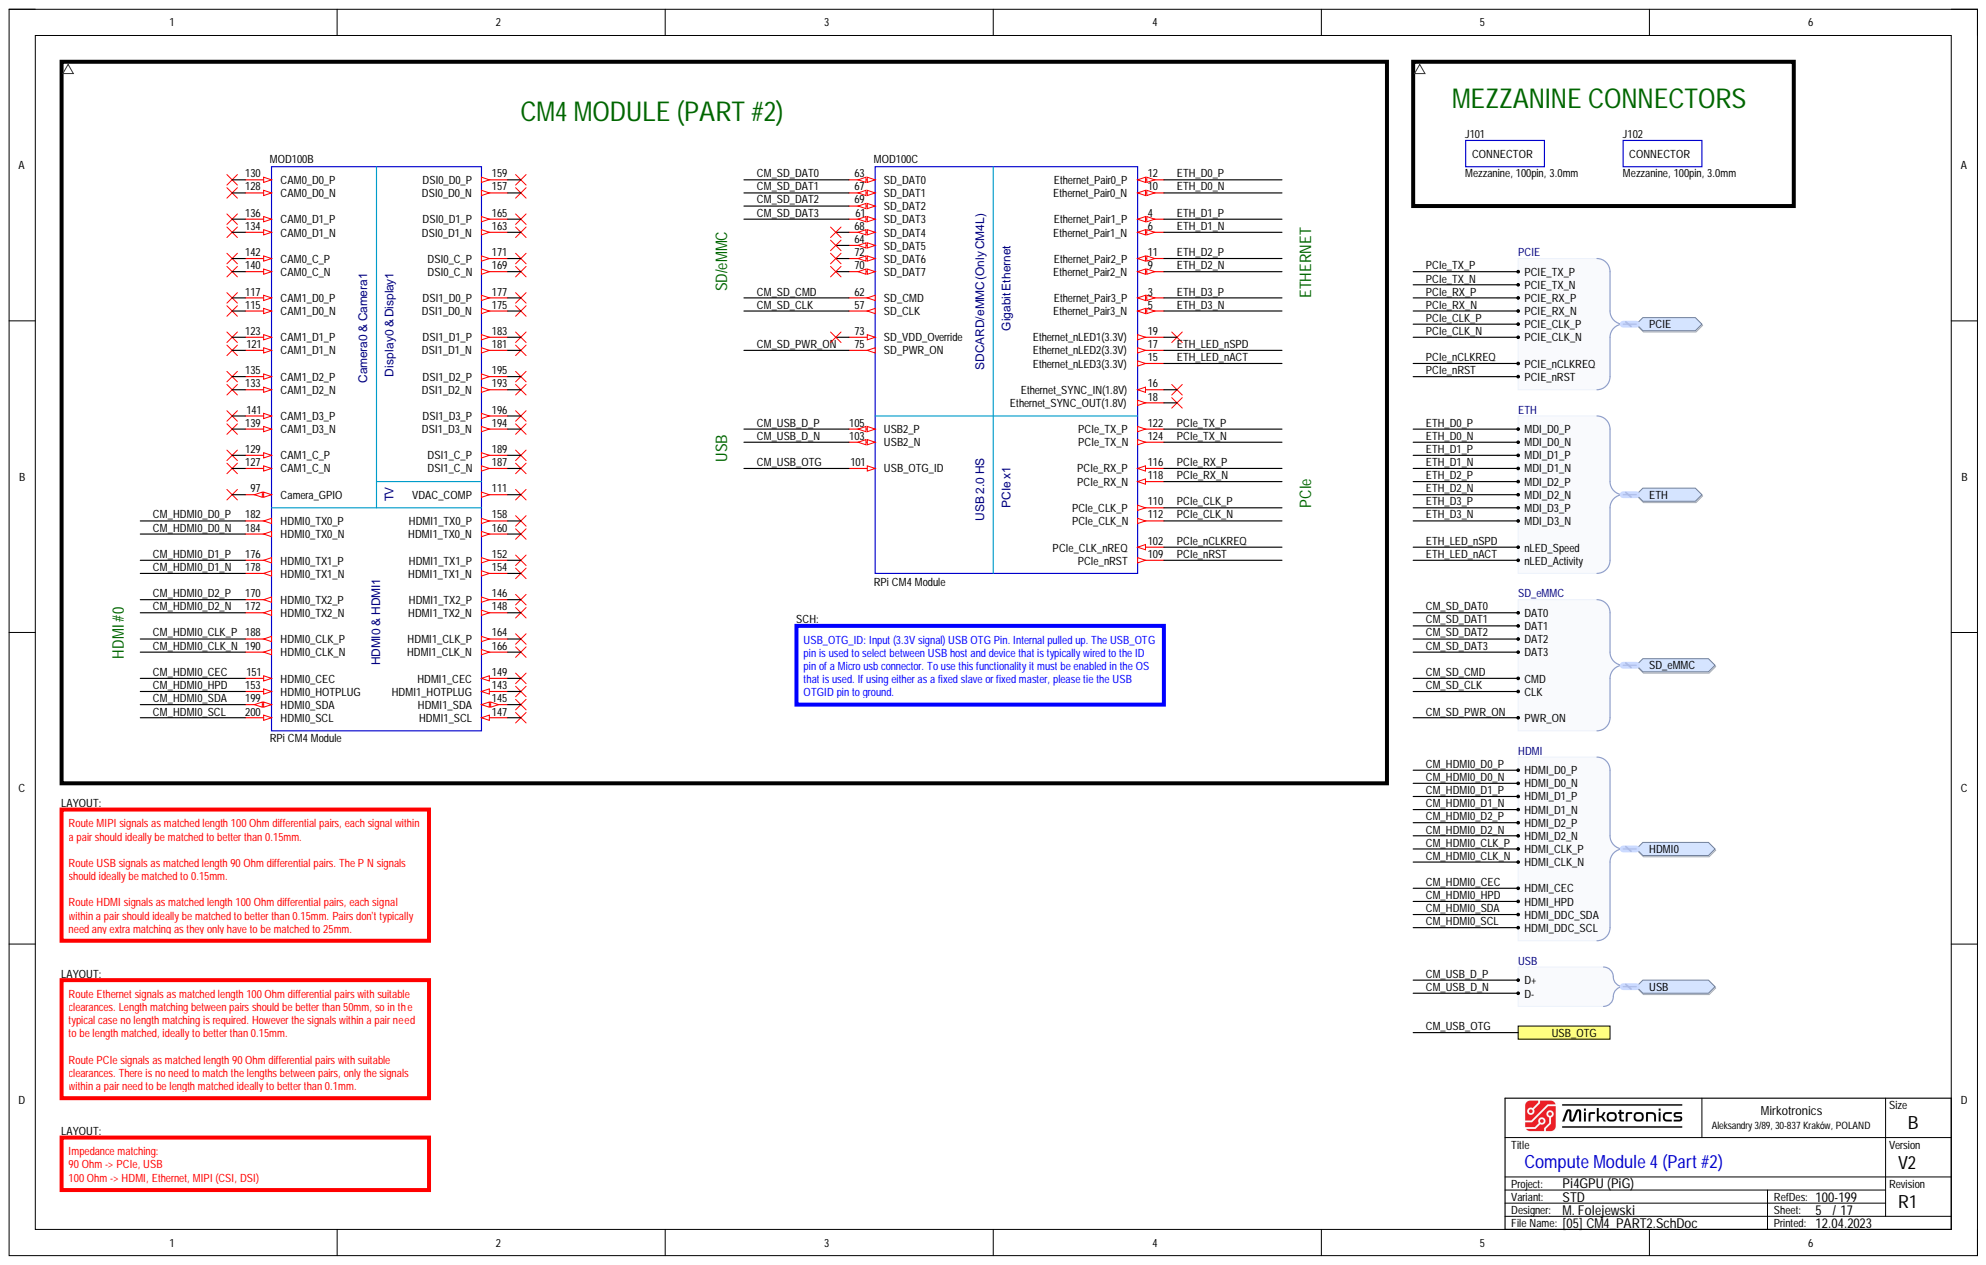
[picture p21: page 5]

SDCARD/eMMC(Only CM4L) USB 2.0 HS

select between USB host and devi
connector. To use

Revi sion R1
Variant: STD
M. Folejewski Designer: | Sheet:
Fi le Name: [05] CM4_PART2.SchDoc | Printed:


D1+ A6 | VBUS
D1- A7 | A9
D2+ B6 | B4

GND VBUS PDC SEC

USER:
USB_OTG line: if USB-C cable is connected
and SW200 jumper has shorted 2-3 pins then
the CM4 becomes a USB Device.

USB DEVICE MODE JUMPER:
1-2 = USB Device disabled (OS BOOT).
2-3 = CM4 connected as USB Device to USB-C cable.

Place the TVS array diodes as close
as possible to the USB-C connector.

connect the IO1A - IO4A
on the connector side.

BOM:
USB 3.1 Type C:
Use XKB Connectivity, MPN = U262-161N-4BVC11.
Description: vertical connector, 16 pins, USB 2.0 only,
SMD version.

LAYOUT:
Route USB signals as matched length 90 Ohm
differential pairs. The P N signals should ideally be
matched to 0.15mm.

Mirkotronics Aleksandry 3/89, 30-837 Kraków, POLAND | Size A4

Title USB-C interface and USB mux | | Version V2

Project: Pi4GPU (PiG) | | Revision R1
Variant: STD | RefDes: 200-249

File Name: [06] USB_C.SchDoc | Printed:

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

SCH:
ILIM resistor = 12k -> current limit set to 2A

Place the TVS array diodes as
close as possible to the HDMI
connector.

connect the IO1A - IO4A
on the connector side.

Place decoupling capacitors as
close as possible to USB hub.

File Name: [07] USB_HUB.SchDoc | Printed:


PCI Express x4 Edge Connector

nd RX diff pairs have PN
ps to improve PCB layout

LAYOU
Route PCIe signals as matched le
suita
only the signals within a pair need to be le
tha

here is no need to match the le

ngth matched ideally to better

Mirkotro n i cs A leksandry 3/89, 30-837 Kraków, POLAND | Siz e A4

Titl e PCIe x4 edge connector (PCIe x1 only) | | Ve rsion V2
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

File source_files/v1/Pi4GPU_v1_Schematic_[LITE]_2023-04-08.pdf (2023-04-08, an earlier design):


Mirkotronics Aleksandry 3/89, 30-837 Kraków, POLAND | Size A3

Title Pi4GPU (PiG) | | Version V1

Revision R1
Variant: LITE
Designer: M. Folejewski
File Name: [01] Cover_page.SchDoc | Printed:


SDIO/eMMC

Title Block diagram | Version V1

Revision R1
Variant: LITE

File Name: [02] Block_diagram.SchDoc | Printed:


Mirkotronics Aleksandry 3/89, 30-837 Kraków, POLAND | Size A4

Title Top schematic | | Version V1

Project: Pi4GPU (PiG) | | Revision R1
Variant: LITE | RefDes: 1-99

Sheet: 3 15 /

File Name: [03] TOP.SchDoc | Printed: 08.04.2023


1 0 7 | 1 8 6
1 0 8 | 1 9 1
1 1 3 | 1 9 2

M i r k o t r o n i c s Aleksa n d ry 3/8 9, 3 0 -8 3 7 K r a k ów, POL AND | S i z e A 3

T i t l e C o m p u te Mo d ule 4 (Part #1) | | V ers i o n V1

P i 4 G P U ( P i G ) Pro j e c t : | | R e v i s i o n R 1
V ari a n t : L I T E | R e fD e s : 1 0 0 -1 9 9
D e s i g n er: M . F o l e j e w s k i | S h e e t : 4 / 1 5
F i l e N ame : [ 0 4 ] C M 4 _ P A R T 1 . S c h D o c | Pri n te d : 0 8 . 0 4 . 2 0 2 3


SDCARD/eMMC(Only CM4L) USB 2.0 HS

Rev i s ion R1
Var iant : LITE | RefDes
M . Folejewski Des igner : | 5 15 Sheet :
Fi le Name: [05] CM4_PART2.SchDoc | Pr inted: 3


USER:
USB_OTG line: if USB-C cable is connected
and SW200 jumper has shorted 2-3 pins then
the CM4 becomes a USB Device.

D1+ A6 | VBUS
D1- A7 | A9
D2+ B6 | B4

GND VBUS PDC SEC

USB DEVICE MODE JUMPER:
1-2 = USB Device disabled (OS BOOT).
2-3 = CM4 connected as USB Device to USB-C cable.

Place the TVS array diodes as close
as possible to the USB-C connector.

connect the IO1A - IO4A
on the connector side.

BOM:
USB 3.1 Type C:
Use XKB Connectivity, MPN = U262-161N-4BVC11.
Description: vertical connector, 16 pins, USB 2.0 only,
SMD version.

LAYOUT:
Route USB signals as matched length 90 Ohm
differential pairs. The P N signals should ideally be
matched to 0.15mm.

Mirkotronics Aleksandry 3/89, 30-837 Kraków, POLAND | Size A4

Title USB-C interface and USB mux | | Version V1

Project: Pi4GPU (PiG) | | Revision R1
Variant: LITE | RefDes: 200-249

File Name: [06] USB_C.SchDoc | Printed:


SCH:
ILIM resistor = 12k #NAME? current limit set to

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

D+ 3 D- 2 GND 4

Place the TVS array diodes as close
as possible to the HDMI connector.

Place decoupling capacitors as
close as possible to USB hub.

File Name: [07] USB_HUB.SchDoc | Printed:


PCI Express x4 Edge Connector

Mirkotro n i c s A leksandry 3/89, 30-837 Krak ów, POLAND | Siz e A4

Titl e PCIe x4 edge connector (PCIe x1 only) | | Ve rsio n V1

Pr oject: Pi4 G PU (PiG ) | | Revisio n
Va ria nt: LIT E R1 | RefDes: 3 0 0 -3 9 9
Desig n e r : M. Foleje w s k i | Sh e et: 8 / 1 5
8] PCIe.S c h D o c File Na m e | Printe 0 8.0 4 . 2 0 2 3 d :


Place the TVS array diodes as close
as possible to the HDMI connector.

connect the IO1A - IO4A
on the connector side.

BOM:
HDMI #0 connector:
Wurth Elektronik, MPN = 685 119 134 923
BOOMELE, MPN = HDMI-001
Description: Type A (Standard), 19 pins, 0.50mm pitch, horizontal, SMD.

LAYOUT:
Route HDMI signals as matched length 100 Ohm differential pairs, each
signal within a pair should ideally be matched to better than 0.15mm. Pairs
don’t typically need any extra matching as they only have to be matched to

Mirkotronics Aleksandry 3/89, 30-837 Kraków, POLAND | Size A4

Title HDMI Interface | | Version V1

Project: Pi4GPU (PiG) | | Revision R1
Variant: LITE | RefDes: 400-449

File Name: [09] HDMI.SchDoc | Printed:


LAYOUT:
Route Ethernet signals as matched length 100 Ohm differential pairs
with suitable clearances. Length matching between pairs should be
better than 50mm, so in the typical case no length matching is required.
However the signals within a pair need to be length matched, ideally to
better than 0.15mm.

BOM:
RJ45 -> compatible connectors:
HanRun, MPN = HR911130A (HY911130A)
Link-PP, MPN = LPJG0806FBNL
Description: 100/1000M RJ45, Tab-down, G/Y LEDs

Place TVS array diodes as close
as possible to RJ45 connector.

Mirkotronics Aleksandry 3/89, 30-837 Kraków, POLAND | Size A4

Title 100/1000M Ethernet interface | | Version V1

Project: Pi4GPU (PiG) | | Revision R1
Variant: LITE | RefDes: 500-599
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

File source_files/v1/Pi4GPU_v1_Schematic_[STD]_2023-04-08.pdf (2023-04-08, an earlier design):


Mirkotronics Aleksandry 3/89, 30-837 Kraków, POLAND | Size A3

Title Pi4GPU (PiG) | | Version V1

Revision R1
Variant: STD_PRO
Designer: M. Folejewski
File Name: [01] Cover_page.SchDoc | Printed:


SDIO/eMMC

Title Block diagram | Version V1

Revision R1
Variant: STD_PRO

File Name: [02] Block_diagram.SchDoc | Printed:


Mirkotronics Aleksandry 3/89, 30-837 Kraków, POLAND | Size A4

Title Top schematic | | Version V1

Project: Pi4GPU (PiG) | | Revision R1
Variant: STD_PRO | RefDes: 1-99

Sheet: 3 15 /

File Name: [03] TOP.SchDoc | Printed: 08.04.2023


1 07 | 1 86
1 08 | 1 91
1 1 3 | 1 92

GPIO27 - GPIO (USER LED2 Red) I2C1 SDA I2C1 SCL

Mi r k o tro n i cs Aleksa nd ry 3/89, 30-837 K ra ków, POLAND | S i z e A 3

T i tl e C o m p u te Mod ule 4 (Part #1) | | Versi on V1

P i 4G P U (P i G ) Proj ect: | | R evi s i on R 1
Vari a n t: S T D_P R O | R efDes : 1 00-1 99
Des i g ner: M. F o l ej ews ki | S hee t: 4 / 1 5
F i l e N ame : [04] C M4_PA R T 1 . S ch Doc | Pri n ted : 08. 04. 2023


SDCARD/eMMC(Only CM4L) USB 2.0 HS

select between USB host and devi
connector. To use

Revi sion R1
Variant: STD_PRO
M. Folejewski Designer: | Sheet:
Fi le Name: [05] CM4_PART2.SchDoc | Printed:


USER:
USB_OTG line: if USB-C cable is connected
and SW200 jumper has shorted 2-3 pins then
the CM4 becomes a USB Device.

D1+ A6 | VBUS
D1- A7 | A9
D2+ B6 | B4

GND VBUS PDC SEC

USB DEVICE MODE JUMPER:
1-2 = USB Device disabled (OS BOOT).
2-3 = CM4 connected as USB Device to USB-C cable.

Place the TVS array diodes as close
as possible to the USB-C connector.

connect the IO1A - IO4A
on the connector side.

BOM:
USB 3.1 Type C:
Use XKB Connectivity, MPN = U262-161N-4BVC11.
Description: vertical connector, 16 pins, USB 2.0 only,
SMD version.

LAYOUT:
Route USB signals as matched length 90 Ohm
differential pairs. The P N signals should ideally be
matched to 0.15mm.

Mirkotronics Aleksandry 3/89, 30-837 Kraków, POLAND | Size A4

Title USB-C interface and USB mux | | Version V1

Project: Pi4GPU (PiG) | | Revision R1
Variant: STD_PRO | RefDes: 200-249

File Name: [06] USB_C.SchDoc | Printed:


SCH:
ILIM resistor = 12k #NAME? current limit set to

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

D+ 3 D- 2 GND 4

Place the TVS array diodes as close
as possible to the HDMI connector.

Place decoupling capacitors as
close as possible to USB hub.

File Name: [07] USB_HUB.SchDoc | Printed:


PCI Express x4 Edge Connector

nd RX diff pairs have PN
ps to improve PCB layout

LAYOU
Route PCIe signals as matched le
suita
only the signals within a pair need to be le
tha

here is no need to match the le

ngth matched ideally to better

Mirkotro n i cs A leksandry 3/89, 30-837 Kraków, POLAND | Siz e A4

Titl e PCIe x4 edge connector (PCIe x1 only) | | Ve rsion V1

Project: Pi4G PU (PiG ) | | Revision
Va ria nt: STD_P R O R1 | RefDes: 300-399
Designer: M. Folejews ki | Sheet: 8 / 1 5
me: [08] PCIe.S ch Doc File Na | Printed 08.04. 2023 :


Place the TVS array diodes as close
as possible to the HDMI connector.

connect the IO1A - IO4A
on the connector side.

BOM:
HDMI #0 connector:
Wurth Elektronik, MPN = 685 119 134 923
BOOMELE, MPN = HDMI-001
Description: Type A (Standard), 19 pins, 0.50mm pitch, horizontal, SMD.

LAYOUT:
Route HDMI signals as matched length 100 Ohm differential pairs, each
signal within a pair should ideally be matched to better than 0.15mm. Pairs
don’t typically need any extra matching as they only have to be matched to

Mirkotronics Aleksandry 3/89, 30-837 Kraków, POLAND | Size A4

Title HDMI Interface | | Version V1

Project: Pi4GPU (PiG) | | Revision R1
Variant: STD_PRO | RefDes: 400-449

File Name: [09] HDMI.SchDoc | Printed:


LAYOUT:
Route Ethernet signals as matched length 100 Ohm differential pairs
with suitable clearances. Length matching between pairs should be
better than 50mm, so in the typical case no length matching is required.
However the signals within a pair need to be length matched, ideally to
better than 0.15mm.

BOM:
RJ45 -> compatible connectors:
HanRun, MPN = HR911130A (HY911130A)
Link-PP, MPN = LPJG0806FBNL
Description: 100/1000M RJ45, Tab-down, G/Y LEDs

Place TVS array diodes as close
as possible to RJ45 connector.
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
